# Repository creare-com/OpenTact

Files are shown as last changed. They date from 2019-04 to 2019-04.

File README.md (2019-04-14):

# OpenTact: Open Source Headset
The goal of this project is to provide the design files, electronics, software, and algorithms to allow you to build your own electronic communications headset.  Multiple headset designs are available here.  We hope that this work will help you get to your goal faster, whether it be research and development or simply fun audio hacking!
## Headset Designs
Three headset designs are included.  As shown below, there is the "Ear" headset, the "Low-Profile" (LoPro) headset, and the "Full-Profile" (FullPro) headset.

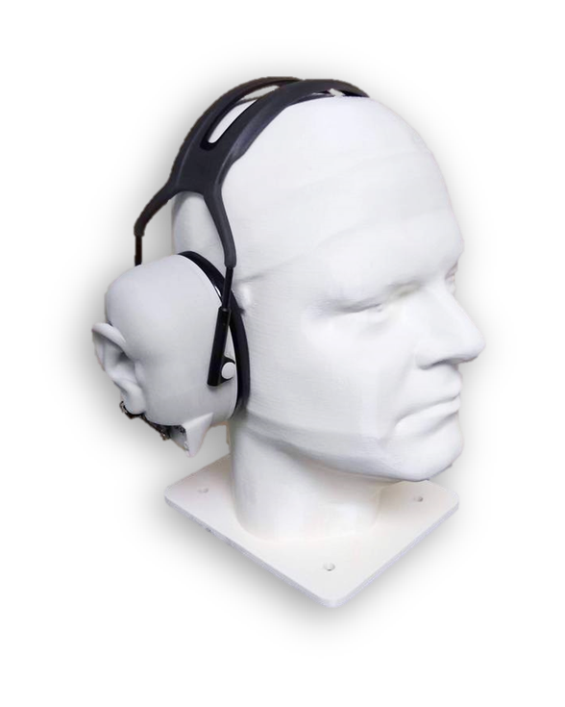
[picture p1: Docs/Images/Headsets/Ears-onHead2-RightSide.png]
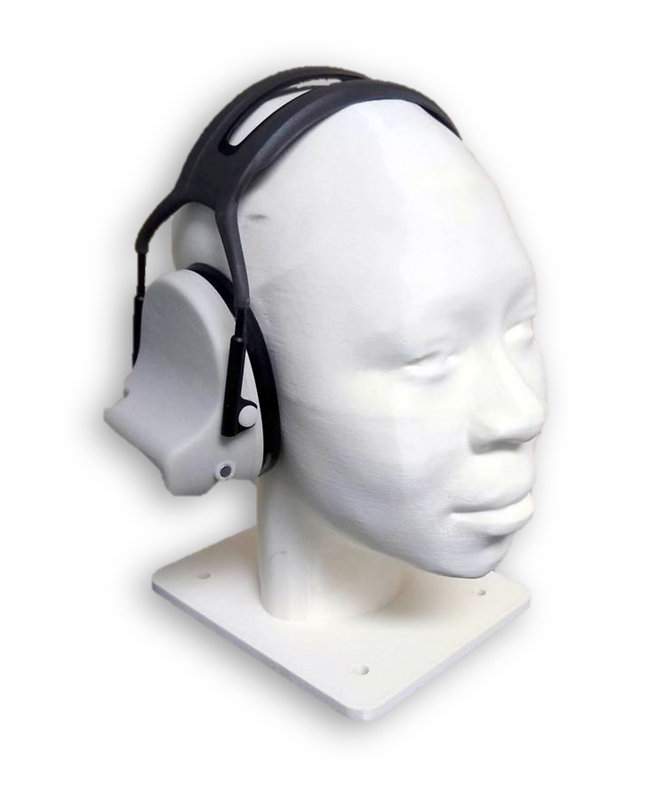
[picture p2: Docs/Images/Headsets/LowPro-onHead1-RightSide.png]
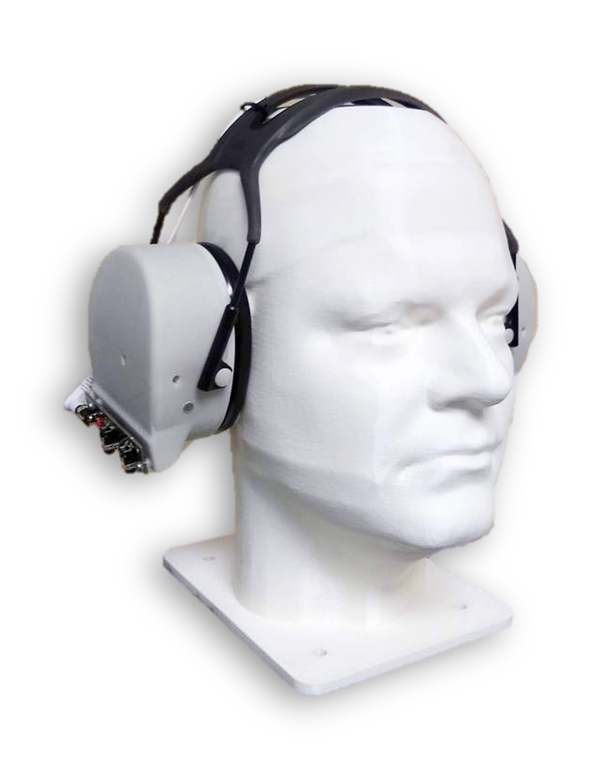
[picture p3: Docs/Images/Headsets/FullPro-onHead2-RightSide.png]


For instructions on how to use this repository to fabricate these headsets, see the [ReadMe.PDF](https://github.com/creare-com/OpenTact/blob/master/ReadMe.pdf)

## License
All of these materials are released under the MIT License.  Use at your own risk.

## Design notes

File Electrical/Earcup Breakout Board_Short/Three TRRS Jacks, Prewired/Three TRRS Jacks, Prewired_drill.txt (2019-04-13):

; NON-PLATED HOLES START AT T1
; THROUGH (PLATED) HOLES START AT T100
M48
INCH
T1C0.129000
T2C0.039361
T100C0.038000
T101C0.015748
%
T1
X015065Y005138
X000959Y000888
T2
X003284Y000871
X017399Y001572
X010174Y000878
X004675Y000871
X003284Y000878
X004674Y000878
X008784Y000878
X017399Y001568
X017399Y002959
X010181Y000871
X017399Y002963
X008791Y000871
T100
X006889Y004888
X001389Y003134
X006889Y003888
X016639Y005388
X001389Y002134
X012639Y005388
X017639Y005388
X001389Y004189
X001389Y005189
X013639Y005388
T101
X014139Y002638
X011889Y002138
X014142Y003890
X003889Y001388
X007887Y003891
X009639Y001388
X010139Y004138
X010889Y004384
X003889Y003638
X004639Y002138
X014889Y002638
X015889Y003539
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

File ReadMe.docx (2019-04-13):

Project: | OpenTact
Title: | Instructions for Building the OpenTact Headset
Date Created: | 4/11/2019

# 1. Contents of the Repository

This repository contains design files that can be used to fabricate headsets with three different styles of earcups. The earcup has a mounting plate for a 40mm speaker and several locations to mount microphones. To preview the earcups, download the eDrawings Viewer (https://www.edrawingsviewer.com/) and open the CAD files under the Mechanical/Preview CAD folder.

## A) Earcup with Pinna: Headset with a plastic, outer ear

## B) Low-Profile Earcup: Headset with low-profile earcups that can be worn under a helmet

## C) Full-Profile Earcup: Headset with earcups similar to off-the-shelf earmuffs

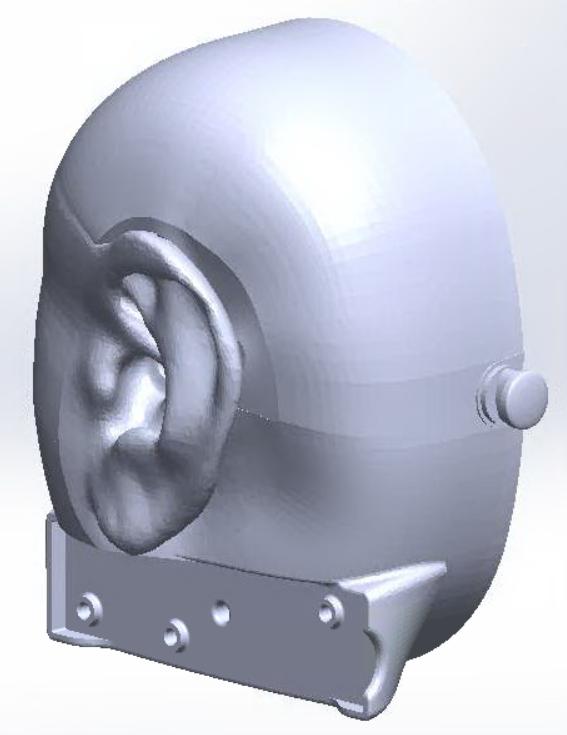
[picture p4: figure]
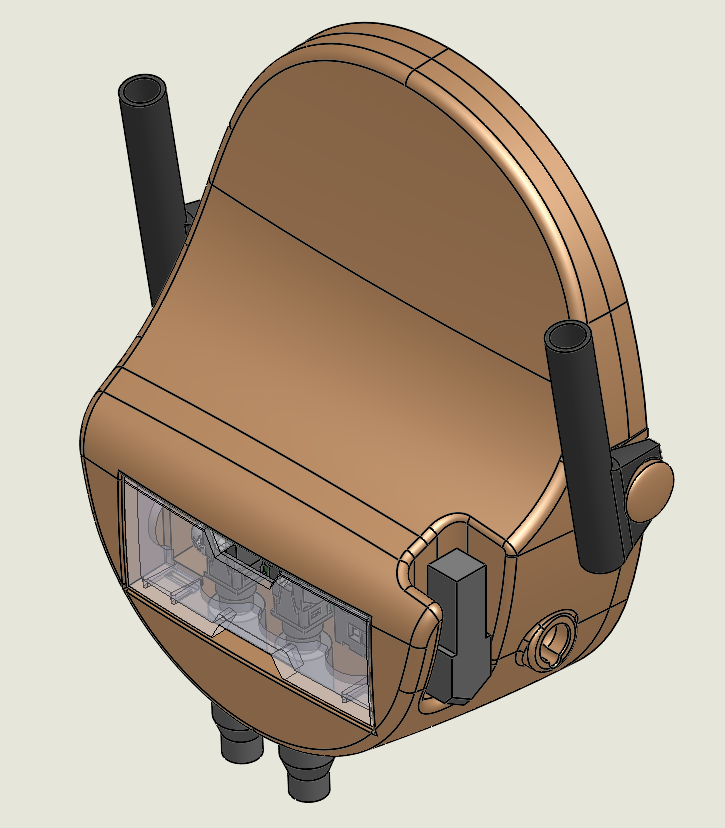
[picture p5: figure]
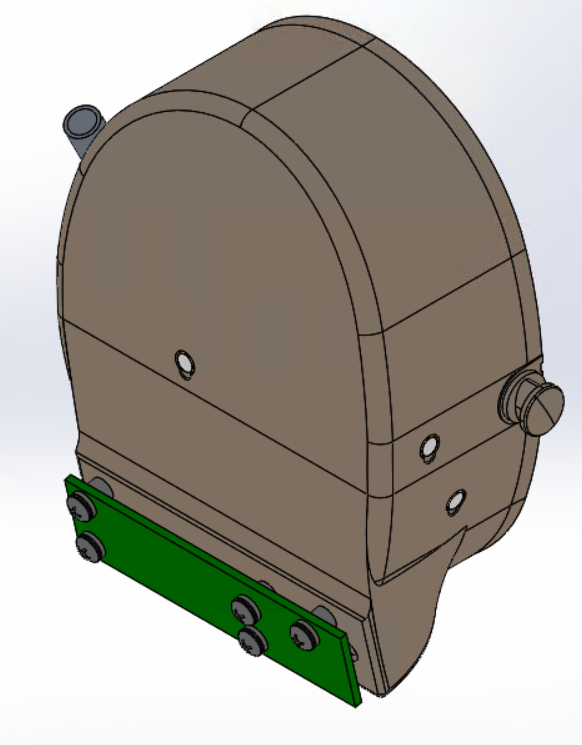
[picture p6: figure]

A B C

## The audio for the headset is processed by the Tympan, which has an audio codec and an Arduino-compatible microcontroller. You can add 2 more additional channels using the AIC Shield, which stacks on top of the Tympan. Two enclosure designs are provide to encompass these boards.

## Tympan Enclosure: Enclosure for the Tympan PCB and battery

## Tympan Enclosure with AIC Shield: Enclosure for the Tympan PCB, battery, and AIC Shield

## The repository is organized by:

## Bill of Materials: List of components and subassemblies

## Mechanical: Solidworks CAD files and STP files for 3D printing

## Electronics: PCB design files and Gerber output files, along with a wiring diagram

## Firmware: Example Arduino sketches written specific for the OpenTact project. For basic sketches on audio processing, start with the Tympan wiki “Getting Started (https://github.com/Tympan/Docs/wiki/Getting-Starting-with-Tympan).”

# 2. Fabricating the Headset Components (also refer to bill of materials)

Mechanical: Most of the mechanical components are 3D-printed using SLS fiber-reinforced nylon (PA12), with the exception of the headband and ear seals, which are taken from a set of commercial ear muffs (3M X4A). The speaker mount accepts 40mm speakers and is compatible with all three earcup styles. If you need to modify the physical components, the CAD design files require Solidworks version 2018 SP4 or later. Otherwise, you can import the STL files and modify them from there.

Electrical: The Tympan processing board can be purchased through https://shop.tympan.org, or fabricated using the design files from this repository. A breakout board is mounted to each earcup to provide a place to solder the mic and speaker wires. The short breakout board is sufficient for projects involving a (1) mic and (1) speaker per side. For more complex projects, the long breakout board accommodates multiple components but requires external jumper wires.

## If using the long breakout board, refer to the wiring diagram in the Electrical folder. Note that the long breakout board is not compatible with the Low-Profile Headset.

## The short breakout board has two sides so that it can be used for both the left and right earcups. Solder (3) TRRS jacks onto the side of the breakout board labeled “J1” in the upper left, which will become the “left” breakout board. These pads correspond to “TRRS-1”, “TRRS-3”, and “TRRS -5”.

## Solder (1) TRRS jack onto the side of the breakout board labeled “J3” in the upper left, which will become the “right” breakout board. These pads correspond to “TRRS-6.”

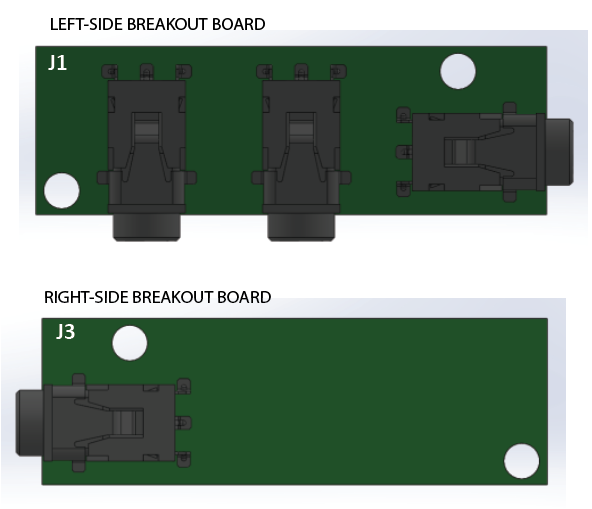
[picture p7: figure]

## Left and right sides of the Short Breakout Board, with TRRS jacks

## If you need to modify the PCBs, the breakout boards for the earcups were created in Fritzing (http://fritzing.org/) and the Tympan PCB and AIC Shield were designed in KiCad (http://kicad-pcb.org/).

# 3. Assembling the Headset

## Microphone: Solder wire leads to the 6mm mic, paying attention to the dot indicating polarity.

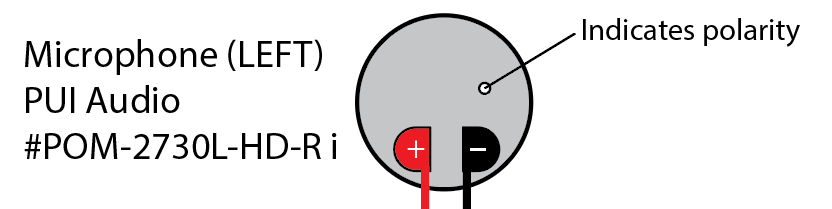
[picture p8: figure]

## In the case of the Earcup with Pinna, the microphone is inserted into the ear canal from inside of the earcup. For the other external microphones, drill out the small pilot hole inside the opening where the microphone will sit to allow wires to be routed inside to the earcup.

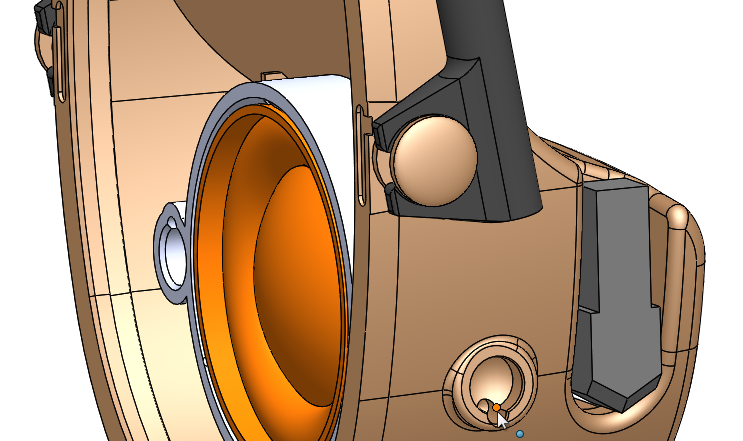
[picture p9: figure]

Drill out pilot hole before inserting the microphone

## Seal the microphone with putty (see BOM) or adhesive, then run the microphone wires through a hole near the bottom of the earcup to the outside, where the breakout board will go. Leave more than 4” of wire outside the earcup to trim back later. Label the wires

## Foam: Trim and insert foam inside the earcups to diffuse the resonating noise from the empty cavity.

Speaker: If using the Low-Profile Earcup, trim back the bottom tab of the speaker mounting plate, as shown in the figure below. Drill a small hole in the middle of the mounting plate to pass wires through, then pass the speaker wires through the mounting plate, then thru the hole near the bottom of the earcup to the outside where the breakout board will go. Leave more than 4” of wire outside the earcup to trim back later. Label the wires. Apply putty (see BOM) to seal the hole in the earcup.

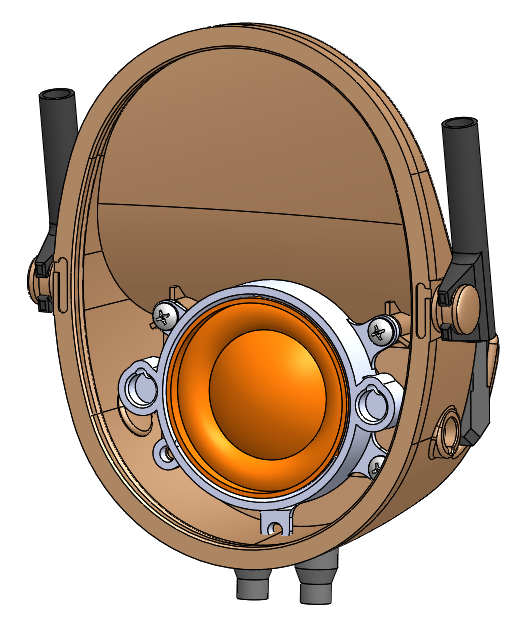
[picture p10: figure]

Trim tab of speaker mount

## Press the speaker into the mounting plate then screw the mounting plate to the earcup. If the speaker is loose inside the mounting plate, apply putty or superglue to secure it.

Ear Seal: Remove the ear seals from the commercial earmuffs and install them onto the new earcups. Hold the earcups against your ears to determine if more foam is needed to diffuse the noise from the empty cavity. Press the ear seal against your face and blow to determine if there are any leaks. Fill any leaks with putty. If you need to remove a stubborn ear seal, use a small screwdriver to pry the ear seal away, inserting a second screwdriver along the gap that is created.

Breakout Boards: Locate the breakout board for the right earcup. Cut the trace indicated in the figure below. Trim the microphone and speaker wires and solder them to the breakout boards. Shown is the outside face of the breakout boards, however, soldering the wires to the inner face provides a cleaner look.

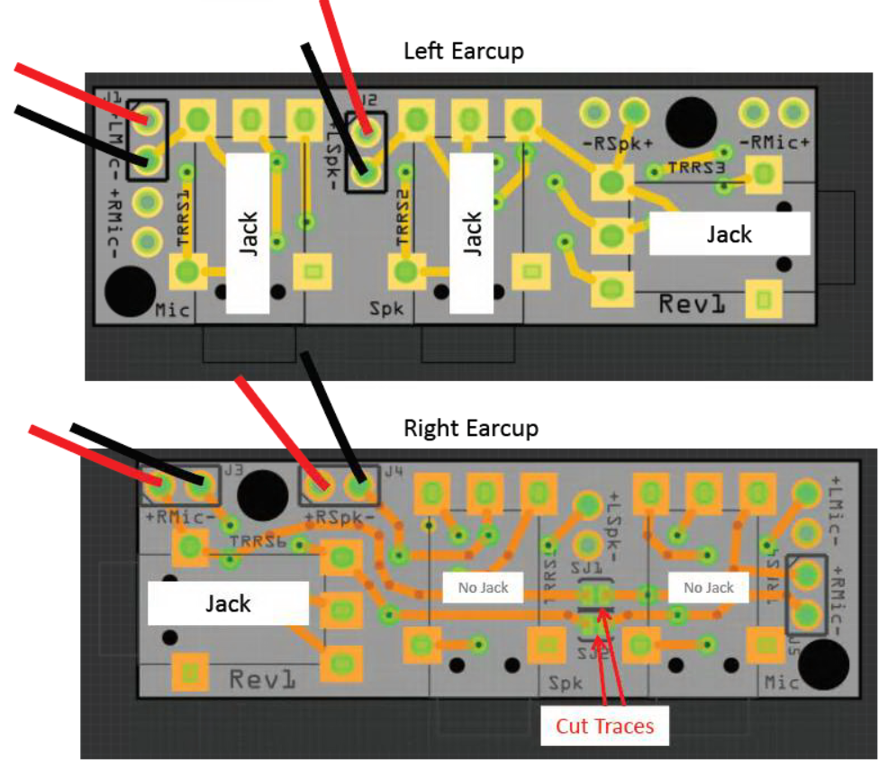
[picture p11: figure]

## Screw the breakout board to the earcup, using washers on top of the board to prevent shorting. If using the long breakout board, place additional plastic washers under the board to provide clearance for the jumper wires.

Cables: The mic and speaker signals from the Tympan are routed to the left earcup using (2) audio cables (3-conductor; TRS). Note that the audio cable with right-angle plugs is 4-conductor (TRRS) and used to bridge the left and right breakout boards. This cable can be shortened (cut and spliced) to better fit the headband.

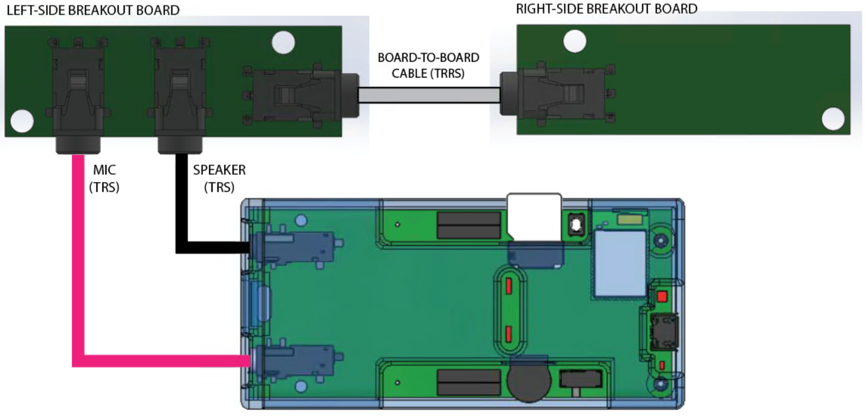
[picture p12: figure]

# 4. Software

Once the components are assembled, follow the “Getting Started (https://github.com/Tympan/Docs/wiki/Getting-Starting-with-Tympan)” guide on the Tympan wiki. This will direct you how to install the Arduino programming environment and the Tympan Audio library. Then move on to the more advanced programs in the Tympan library, or check out the OpenTact-specific programs included in this repository.

OpenTact Readme.docx (Rev-1.1) 1 of 6

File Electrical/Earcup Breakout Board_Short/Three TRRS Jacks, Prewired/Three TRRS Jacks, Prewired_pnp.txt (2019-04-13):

*Pick And Place List
*Company=
*Author=
*eMail=
*
*Project=Three TRRS Jacks, Prewired
*Date=18:40:02
*CreatedBy=Fritzing 0.9.3b.04.19.5c895d327c44a3114e5fcc9d8260daf0cbb52806
*
*
*Coordinates in mm, always center of component
*Origin 0/0=Lower left corner of PCB
*Rotation in degree (0-360, math. pos.)
*
*No;Value;Package;X;Y;Rotation;Side;Name
1;;;2.43811;-2.25756;0;Bottom;Hole3
2;;RC-5325A [SMD];24.0715;-6.07312;-90;Top;TRRS2
3;;;11.7844;-10.5127;0;Bottom;Via13
4;;;13.6894;-6.70265;0;Bottom;Via4
5;;;40.3594;-11.1477;0;Bottom;Via8
6;;;38.3282;-1.2886;0;Bottom;TXT2
7;;;33.579;-11.5736;0;Bottom;TXT6
8;;;35.9217;-9.88076;0;Bottom;Via9
9;;;24.4844;-3.52765;0;Bottom;Via15
10;;RC-5325A [SMD];10.1161;-6.05339;90;Bottom;TRRS4
11;;;1.6819;-6.33256;-90;Bottom;TXT6
12;;;9.87937;-9.24265;0;Bottom;Via14
13;;;38.2662;-13.0526;0;Bottom;Hole5
14;;;33.3699;-11.5316;0;Bottom;TXT6
15;;;6.06937;-9.87765;0;Bottom;Via10
16;;;29.5644;-9.24265;0;Bottom;Via7
17;;RC-5325A [SMD];24.1016;-6.05339;90;Bottom;TRRS5
18;;THT;17.4995;-11.1476;0;Bottom;J2
19;;;35.9144;-6.70265;0;Bottom;Via5
20;;;40.3594;-8.99035;0;Bottom;Via3
21;;;43.5903;-11.6488;0;Bottom;TXT6
22;;;1.81116;-12.0857;-90;Bottom;TXT6
23;;RC-5325A [SMD];40.354;-5.75394;180;Top;TRRS3
24;;;11.7844;-5.43265;0;Bottom;Via1
25;;sj_2s-trace;16.9915;-6.70256;180;Bottom;SJ1
26;;;15.2905;-10.9798;90;Bottom;TXT6
27;;THT;3.52947;-11.911;0;Bottom;J1
28;;sj_2s-trace;16.9915;-4.79756;180;Bottom;SJ2
29;;;1.30292;-6.61144;90;Bottom;TXT6
30;;THT;3.52947;-6.69211;0;Bottom;J5
31;;;15.9745;-11.0578;-90;Bottom;TXT6
32;;;5.09801;-0.981822;0;Bottom;TXT6
33;;;27.6582;-11.1361;0;Bottom;Via20
34;;;18.9077;-0.953036;0;Bottom;TXT6
35;;;1.37521;-11.6223;90;Bottom;TXT6
36;;;18.8234;-1.05157;0;Bottom;TXT6
37;;;30.1994;-5.43265;0;Bottom;Via2
38;;;38.274;-1.13084;0;Bottom;TXT2
39;;;20.0334;-9.88358;0;Bottom;Via11
40;;;5.13193;-0.929081;0;Bottom;TXT6
41;;RC-5325A [SMD];10.1015;-6.07312;-90;Top;TRRS1
42;;;25.7544;-7.97265;0;Bottom;Via18
43;;RC-5325A [SMD];40.354;-5.75704;0;Bottom;TRRS6
44;;;23.8494;-10.5127;0;Bottom;Via16
45;;THT;33.3745;-13.6876;90;Bottom;J4
46;;THT;43.5345;-13.6876;90;Bottom;J3
47;;;43.5333;-11.5457;0;Bottom;TXT6
48;;;9.87937;-3.52765;0;Bottom;Via12
49;;;37.8194;-6.70265;0;Bottom;Via6
50;;;25.7544;-10.5127;0;Bottom;Via19

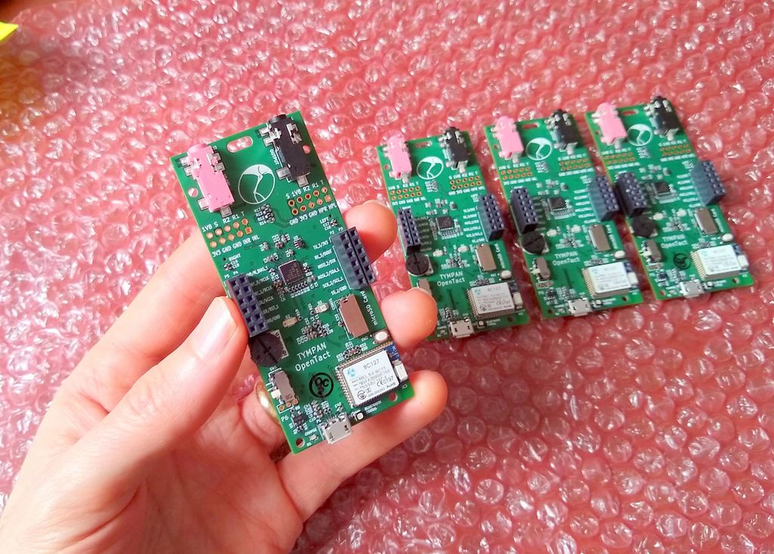
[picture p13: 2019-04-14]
Docs/Images/Electronics/Tympan RevD3 - Hand.jpg

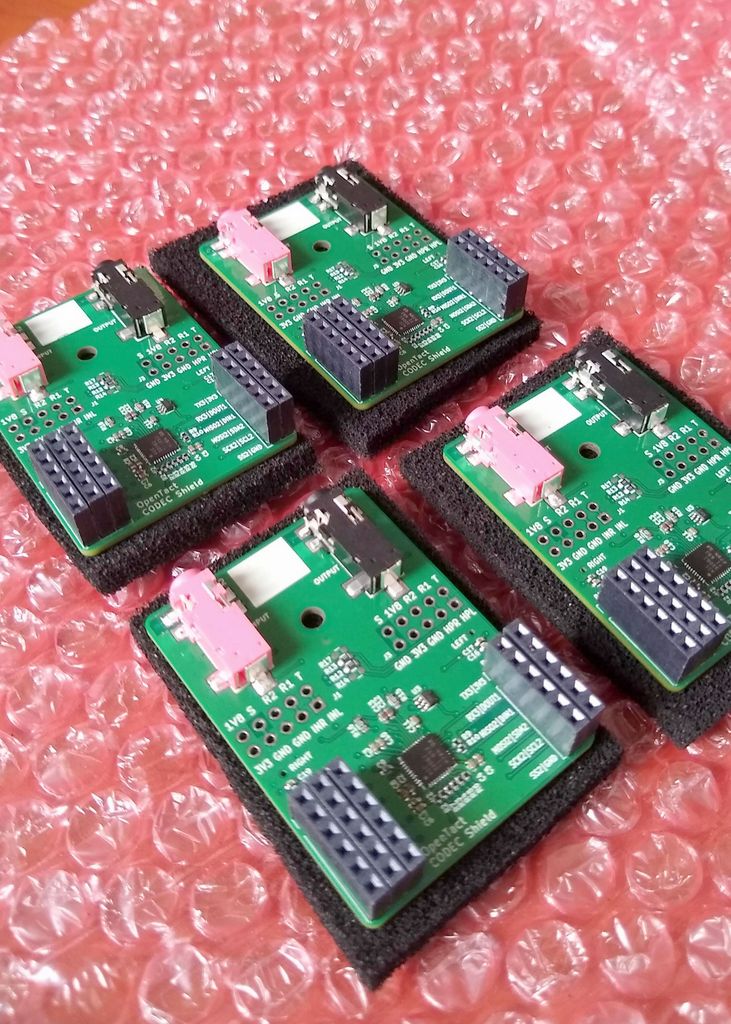
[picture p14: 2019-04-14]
Docs/Images/Electronics/Tympan AIC Shields.jpg

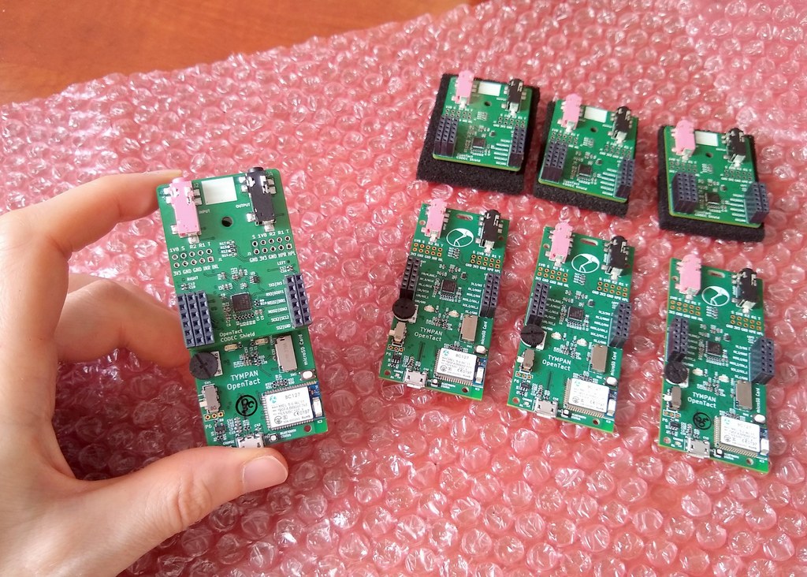
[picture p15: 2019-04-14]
Docs/Images/Electronics/Tympan 4-Channel.jpg

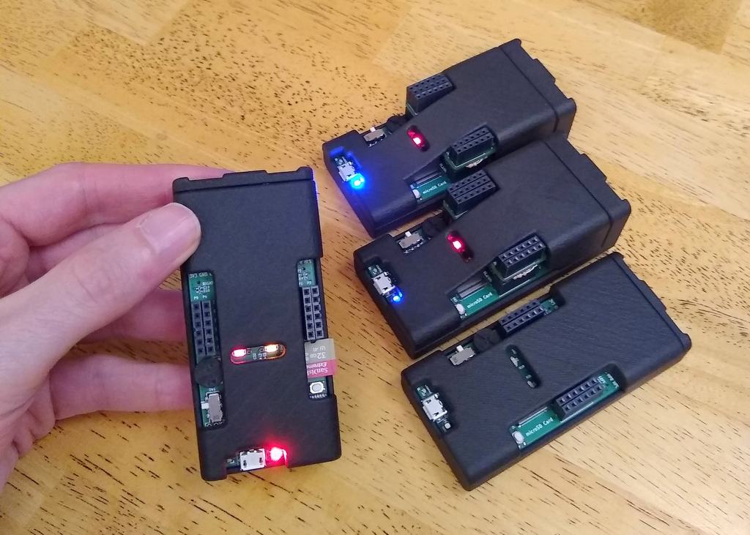
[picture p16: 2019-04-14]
Docs/Images/Electronics/Tympan_RevD3_inEnclosures_Hand.jpg

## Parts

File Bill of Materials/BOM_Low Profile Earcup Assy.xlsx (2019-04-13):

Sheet: EARCUP_WITH PINNA
Project: | OpenTact
Title: | Bill of Materials for EARCUP_WITH PINNA
Date Created: | 2019-04-11
Earcup Revision: | C
Notes: | BOM captures a full headset (left and right).
Line # | Title | Description | Manufacturer | Manuf. Part # | Vendor | Vendor Part # | Unit Cost | Quantity | Subtotal | Notes
1 | EARCUP_BODY_LEFT_WITH_PINNA_REV-C | 3D-printed earcup - Left | PROTOLABS | N/A | N/A | N/A | $128.00 | 1 | $128.00 | Selective Laser Sintering; PA 12 40% Glass Filled Nylon; 0.004" layers
2 | EARCUP_BODY_RIGHT_WITH_PINNA_REV-C | 3D-printed earcup - Right | PROTOLABS | N/A | N/A | N/A | $128.00 | 1 | $128.00 | Selective Laser Sintering; PA 12 40% Glass Filled Nylon; 0.004" layers
4 | PLASTITE SCREW_SZ-4_0250-LG_SS | Screw | N/A | N/A | McMaster | 99461A282 (https://www.mcmaster.com/99461a282) | $0.38 | 10 | $3.75 | Screws for mouning PCB and speaker mounts
5 | WASHER_SZ-4_NYLON | Plastic Washer | N/A | N/A | McMaster | 90295A059 (https://www.mcmaster.com/90295A059) | $0.05 | 4 | $0.20
6 | POLYURETHANE_FOAM_24x24x0500-THK | Foam for diffusing sound | N/A | N/A | McMaster | 86225K15 (https://www.mcmaster.com/86225K15) | $13.86 | 0.1 | $1.39
7 | HEADBAND & 2_EARSEALS_27DB | Parts from retail earmuffs | 3M | X4A | Amazon | B00CPCHADQ (https://www.amazon.com/Peltor-Over-Head-Earmuffs-Black/dp/B00CPCHADQ?s=gateway) | $25.94 | 1 | $25.94
8 | MOUNT_FOR_40MM_SPEAKER | Speaker mount | PROTOLABS | N/A | N/A | N/A | $34.45 | 2 | $68.89 | Selective Laser Sintering; PA 12 40% Glass Filled Nylon; 0.004" layers
9 | SEALING_PUTTY | Putty for sealing the earcup | Parker | PP-22 | Grainger | 4E307 | $14.68 | 0.1 | $1.47
10 | SPEAKER_40MM-OD | Speaker | Beats | Studio 2.0 | EarPhoneDIYLabs (https://www.earphonediylabs.com/index.php/product-category/headphone-drivers/) | N/A | $16.99 | 2 | $33.98
11 | MIC_ELECTRET_6MM-OD | Microphone | PUI Audio | POM-2730L-HD-R | Digikey | 668-1598-ND (https://www.digikey.com/product-detail/en/pui-audio-inc/POM-2730L-HD-R/668-1598-ND/7898330) | $3.14 | 2 | $6.28
12 | AUDIO_CABLE_3.5MM_TRS_MALE-MALE_3FT_RED | Mic Cable | IXCC | N/A | Amazon | B077VPB1WZ (https://www.amazon.com/iXCC-Nylon-Braided-Connectors-Tangle-Free-Smartphones/dp/B077VPB1WZ?s=electronics) | $3.50 | 1 | $3.50
13 | AUDIO_CABLE_3.5MM_TRS_MALE-MALE_3FT_BLK | Speaker Cable | IXCC | N/A | Amazon | B06XWWY7NW (https://www.amazon.com/iXCC-Nylon-Braided-Connectors-Tangle-Free-Smartphones/dp/B06XWWY7NW?s=electronics) | $4.00 | 1 | $4.00
14 | AUDIO_CABLE_3.5MM_TRRS_MALE-MALE_?FT_WHT | Left-Right Cable | N/A | N/A | Sparkfun | CAB-14164 (https://www.sparkfun.com/products/14164) | $2.50 | 1 | $2.50 | Cable requires shortening to fit between right and left earcup
15 | SHORT_BREAKOUT_BOARD | Breakout Board | OSH Park (https://oshpark.com/) | N/A | N/A | N/A | $3.67 | 2 | $7.33 | 2-Layer FR4
16 | LONG_BREAKOUT_BOARD | Breakout Board | OSH Park (https://oshpark.com/) | N/A | N/A | N/A | $6.13 | 0 | $0.00 | Optional 2-Layer FR4
17 | AUDIO_JACK_3.5MM_TRRS_RA | Audio Jack (TRRS) | LUMBERG | 1503 13 VP3 | NEWARK | 54M1764 (https://www.newark.com/lumberg/1503-13-vp3/connector-rca-phono-jack-4-position/dp/54M1764) | $1.20 | 4 | $4.80
TOTAL |  |  |  |  |  |  |  |  | $420.01

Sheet: EARCUP_LOW-PROFILE
Project: | OpenTact
Title: | Bill of Materials for EARCUP_LOW PROFILE
Date Created: | 2019-04-11
Earcup Revision: | C
Notes: | BOM captures a full headset (left and right).
Line # | Title | Description | Manufacturer | Manuf. Part # | Vendor | Vendor Part # | Unit Cost | Quantity | Subtotal | Notes
1 | EARCUP_BODY_LEFT_LOW_PROFILE_REV-C | 3D-printed earcup - Left | PROTOLABS | N/A | N/A | N/A | $135.97 | 1 | $135.97 | Selective Laser Sintering; PA 12 40% Glass Filled Nylon; 0.004" layers
2 | EARCUP_BODY_RIGHT_LOW_PROFILE_REV-C | 3D-printed earcup - Right | PROTOLABS | N/A | N/A | N/A | $135.97 | 1 | $135.97 | Selective Laser Sintering; PA 12 40% Glass Filled Nylon; 0.004" layers
3 | PCB_COVER_LOW_PROFILE | 3D-printed cover | PROTOLABS | N/A | N/A | N/A | $28.35 | 2 | $56.70 | Selective Laser Sintering; PA 12 40% Glass Filled Nylon; 0.004" layers
4 | PLASTITE SCREW_SZ-4_0250-LG_SS | Screw | N/A | N/A | McMaster | 99461A282 (https://www.mcmaster.com/99461a282) | $0.38 | 10 | $3.75 | Screws for mouning PCB and speaker mounts
5 | WASHER_SZ-4_NYLON | Plastic Washer | N/A | N/A | McMaster | 90295A059 (https://www.mcmaster.com/90295A059) | $0.05 | 4 | $0.20
6 | POLYURETHANE_FOAM_24x24x0500-THK | Foam for diffusing sound | N/A | N/A | McMaster | 86225K15 (https://www.mcmaster.com/86225K15) | $13.86 | 0.1 | $1.39
7 | HEADBAND & 2_EARSEALS_27DB | Parts from retail earmuffs | 3M | X4A | Amazon | B00CPCHADQ (https://www.amazon.com/Peltor-Over-Head-Earmuffs-Black/dp/B00CPCHADQ?s=gateway) | $25.94 | 1 | $25.94
8 | MOUNT_FOR_40MM_SPEAKER | Speaker mount | PROTOLABS | N/A | N/A | N/A | $34.45 | 2 | $68.89 | Selective Laser Sintering; PA 12 40% Glass Filled Nylon; 0.004" layers NOTE! BOTTOM SPEAKER MOUNT MUST BE TRIMMED
9 | SEALING_PUTTY | Putty for sealing the earcup | Parker | PP-22 | Grainger | 4E307 | $14.68 | 0.1 | $1.47
10 | SPEAKER_40MM-OD | Speaker | Beats | Studio 2.0 | EarPhoneDIYLabs (https://www.earphonediylabs.com/index.php/product-category/headphone-drivers/) | N/A | $16.99 | 2 | $33.98
11 | MIC_ELECTRET_6MM-OD | Microphone | PUI Audio | POM-2730L-HD-R | Digikey | 668-1598-ND (https://www.digikey.com/product-detail/en/pui-audio-inc/POM-2730L-HD-R/668-1598-ND/7898330) | $3.14 | 2 | $6.28
12 | AUDIO_CABLE_3.5MM_TRS_MALE-MALE_3FT_RED | Mic Cable | IXCC | N/A | Amazon | B077VPB1WZ (https://www.amazon.com/iXCC-Nylon-Braided-Connectors-Tangle-Free-Smartphones/dp/B077VPB1WZ?s=electronics) | $3.50 | 1 | $3.50
13 | AUDIO_CABLE_3.5MM_TRS_MALE-MALE_3FT_BLK | Speaker Cable | IXCC | N/A | Amazon | B06XWWY7NW (https://www.amazon.com/iXCC-Nylon-Braided-Connectors-Tangle-Free-Smartphones/dp/B06XWWY7NW?s=electronics) | $4.00 | 1 | $4.00
14 | AUDIO_CABLE_3.5MM_TRRS_MALE-MALE_?FT_WHT | Left-Right Cable | N/A | N/A | Sparkfun | CAB-14164 (https://www.sparkfun.com/products/14164) | $2.50 | 1 | $2.50 | Cable requires shortening to fit between right and left earcup
15 | SHORT_BREAKOUT_BOARD | Breakout Board | OSH Park (https://oshpark.com/) | N/A | N/A | N/A | $3.67 | 2 | $7.33 | 2-Layer FR4
16 | AUDIO_JACK_3.5MM_TRRS_RA | Audio Jack (TRRS) | LUMBERG | 1503 13 VP3 | NEWARK | 54M1764 (https://www.newark.com/lumberg/1503-13-vp3/connector-rca-phono-jack-4-position/dp/54M1764) | $1.20 | 4 | $4.80
TOTAL |  |  |  |  |  |  |  |  | $492.65

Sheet: EARCUP_FULL-PROFILE
Project: | OpenTact
Title: | Bill of Materials for EARCUP_FULL-PROFILE
Date Created: | 2019-04-11
Earcup Revision: | C
Notes: | BOM captures a full headset (left and right).
Line # | Title | Description | Manufacturer | Manuf. Part # | Vendor | Vendor Part # | Unit Cost | Quantity | Subtotal | Notes
1 | EARCUP_BODY_LEFT_FULL_PROFILE_REV-C | 3D-printed earcup - Left | PROTOLABS | N/A | N/A | N/A | $165.00 | 1 | $165.00 | Selective Laser Sintering; PA 12 40% Glass Filled Nylon; 0.004" layers
2 | EARCUP_BODY_RIGHT_FULL_PROFILE_REV-C | 3D-printed earcup - Right | PROTOLABS | N/A | N/A | N/A | $165.00 | 1 | $165.00 | Selective Laser Sintering; PA 12 40% Glass Filled Nylon; 0.004" layers
4 | PLASTITE SCREW_SZ-4_0250-LG_SS | Screw | N/A | N/A | McMaster | 99461A282 (https://www.mcmaster.com/99461a282) | $0.38 | 10 | $3.75 | Screws for mouning PCB and speaker mounts
5 | WASHER_SZ-4_NYLON | Plastic Washer | N/A | N/A | McMaster | 90295A059 (https://www.mcmaster.com/90295A059) | $0.05 | 4 | $0.20
6 | POLYURETHANE_FOAM_24x24x0500-THK | Foam for diffusing sound | N/A | N/A | McMaster | 86225K15 (https://www.mcmaster.com/86225K15) | $13.86 | 0.1 | $1.39
7 | HEADBAND & 2_EARSEALS_27DB | Parts from retail earmuffs | 3M | X4A | Amazon | B00CPCHADQ (https://www.amazon.com/Peltor-Over-Head-Earmuffs-Black/dp/B00CPCHADQ?s=gateway) | $25.94 | 1 | $25.94
8 | MOUNT_FOR_40MM_SPEAKER | Speaker mount | PROTOLABS | N/A | N/A | N/A | $34.45 | 2 | $68.89 | Selective Laser Sintering; PA 12 40% Glass Filled Nylon; 0.004" layers
9 | SEALING_PUTTY | Putty for sealing the earcup | Parker | PP-22 | Grainger | 4E307 | $14.68 | 0.1 | $1.47
10 | SPEAKER_40MM-OD | Speaker | Beats | Studio 2.0 | EarPhoneDIYLabs (https://www.earphonediylabs.com/index.php/product-category/headphone-drivers/) | N/A | $16.99 | 2 | $33.98
11 | MIC_ELECTRET_6MM-OD | Microphone | PUI Audio | POM-2730L-HD-R | Digikey | 668-1598-ND (https://www.digikey.com/product-detail/en/pui-audio-inc/POM-2730L-HD-R/668-1598-ND/7898330) | $3.14 | 2 | $6.28
12 | AUDIO_CABLE_3.5MM_TRS_MALE-MALE_3FT_RED | Mic Cable | IXCC | N/A | Amazon | B077VPB1WZ (https://www.amazon.com/iXCC-Nylon-Braided-Connectors-Tangle-Free-Smartphones/dp/B077VPB1WZ?s=electronics) | $3.50 | 1 | $3.50
13 | AUDIO_CABLE_3.5MM_TRS_MALE-MALE_3FT_BLK | Speaker Cable | IXCC | N/A | Amazon | B06XWWY7NW (https://www.amazon.com/iXCC-Nylon-Braided-Connectors-Tangle-Free-Smartphones/dp/B06XWWY7NW?s=electronics) | $4.00 | 1 | $4.00
14 | AUDIO_CABLE_3.5MM_TRRS_MALE-MALE_?FT_WHT | Left-Right Cable | N/A | N/A | Sparkfun | CAB-14164 (https://www.sparkfun.com/products/14164) | $2.50 | 1 | $2.50 | Cable requires shortening to fit between right and left earcup
15 | SHORT_BREAKOUT_BOARD | Breakout Board | OSH Park (https://oshpark.com/) | N/A | N/A | N/A | $3.67 | 2 | $7.33 | 2-Layer FR4
16 | LONG_BREAKOUT_BOARD | Breakout Board | OSH Park (https://oshpark.com/) | N/A | N/A | N/A | $6.13 | 0 | $0.00 | Optional 2-Layer FR4
17 | AUDIO_JACK_3.5MM_TRRS_RA | Audio Jack (TRRS) | LUMBERG | 1503 13 VP3 | NEWARK | 54M1764 (https://www.newark.com/lumberg/1503-13-vp3/connector-rca-phono-jack-4-position/dp/54M1764) | $1.20 | 4 | $4.80
TOTAL |  |  |  |  |  |  |  |  | $494.01

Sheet: TYMPAN
Project: | OpenTact
Title: | Bill of Materials for Tympan Assy
Date Created: | 2019-04-11
Line # | Title | Description | Manufacturer | Manuf. Part # | Vendor | Vendor Part # | Unit Cost | Quantity | Subtotal | Notes
1 | TYMPAN PCB | Audio Processor | Tympan | Tympan Rev D (https://shop.tympan.org/) | Tympan | Tympan Rev D (https://shop.tympan.org/) | $299.00 | 1 | $299.00
2 | ENCLOSURE FOR TYMPAN_TOP_REV-B | Enclosure | Protolabs | N/A | N/A | N/A | $55.58 | 1 | $55.58 | Selective Laser Sintering; PA 12 in Black; 0.004" layers
3 | ENCLOSURE FOR TYMPAN_BOTTOM_REV-B | Enclosure | Protolabs | N/A | N/A | N/A | $64.43 | 1 | $64.43 | Selective Laser Sintering; PA 12 in Black; 0.004" layers
4 | TYMPAN AIC SHIELD | Audio Shield PCB | Tympan | Tympan AIC Shield | N/A | Tympan AIC Shield | $0.00 | 0 | $0.00 | Optional audio shield that adds two additonal channels
5 | ENCLOSURE FOR TYMPAN WITH SHIELD_TOP_REV-B | Enclosure | Tympan | N/A | N/A | N/A | $77.73 | 0 | $0.00 | Optional; Selective Laser Sintering; PA 12 in Black; 0.004" layers
6 | ENCLOSURE FOR TYMPAN WITH SHIELD_BOTTOM_REV-B | Enclosure | Tympan | N/A | N/A | N/A | $87.08 | 0 | $0.00 | Optional; Selective Laser Sintering; PA 12 in Black; 0.004" layers
TOTAL |  |  |  |  |  |  |  |  | $419.01

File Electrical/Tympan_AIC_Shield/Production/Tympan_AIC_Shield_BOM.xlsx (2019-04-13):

Item | Reference | Package | Quantity | Value | Manufacturer | Part Number | Notes
1 | C23,C2,C8,C12,C13,C24,C25,C26 | C_0402 | 8 | 2.2uF | Murata | GRT155C71A225KE13D
2 | C3,C5,C7,C10,C16,C18 | C_0402 | 6 | 0.1uF | TDK Corporation | C1005X7R1H104K050BB
3 | C4,C6,C11 | C_0402 | 3 | 10uF | Murata | GRM155C80J106ME11J
4 | C9,C17,C19 | C_0402 | 3 | 1uF | Murata | GRM155C81C105KE15D
5 | J1 | SJ-3523-SMT-TR | 1 | Phone Out | CUI Inc | SJ-3523-SMT-TR
6 | J2 | SJ-3524-SMT-TR | 1 | Mic In | CUI Inc | SJ-3524-SMT-TR-PI
7 | MIC2,MIC1 | SPM0687LR5H-1 | 2 | DNP | DNP | DNP | DNP
8 | P5,P6 | Pin_Header_Straight_1x06_Pitch2.54mm | 2 | CONN_01X06 | Samtec | SSW-106-01-G-S
9 | P3,P4,P2,P1 | Pin_Header_Straight_1x06_Pitch2.54mm | 4 | CONN_01X06 | Samtec | SSW-106-03-T-S
10 | R1,R8 | R_0402 | 2 | 4K7 | Yageo | RC0603FR-074K7L
11 | R12,R13 | C_0603 | 2 | 0R | Vishay Dale | CRCW06030000Z0EA
12 | R14,R17 | C_0603 | 2 | DNP | DNP | DNP | DNP
13 | R15,R16 | C_0603 | 2 | 2.2K | Yageo | RC0603FR-072K2L
14 | R2,R3,R4,R5,R6,R7,R9,R10 | R_0402 | 8 | 33R | Yageo | RC0402FR-0733RL
15 | U2 | UQFN-40-1EP_5x5mm_Pitch0.4mm | 1 | CODEC | Texas Instrument | TLV320AIC3206IRSBT
16 | U3 | SOT-353_SC-70-5 | 1 | Analog Switch IC | Texas Instrument | TS5A3166DCKR

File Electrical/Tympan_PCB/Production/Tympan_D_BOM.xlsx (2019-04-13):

Item | Reference | Package | Quantity | Value | Manufacturer | Part Number | Notes
1 | BT1 | 4UCON-0217-20519 | 1 | 4UCON-20519 | 4UCON | 20519 | Consigned by Solutions
2 | C1,C3,C5,C7,C10,C14,C16,C18,C28,C29,C42 | C_0402 | 11 | 0.1uF | TDK Corporation | C1005X7R1H104K050BB
3 | C2,C8,C12,C13,C23,C24,C25,C26,C27,C32,C33,C37,C39 | C_0402 | 13 | 2.2uF | Murata | GRT155C71A225KE13D
4 | C30,C31 | C_0402 | 2 | 10nF | Yageo | AC0402KPX7R9BB103
5 | C35 | C_0402 | 1 | 4.7uF | TDK Corporation | C1005X5R1A475K050BC
6 | C4,C6,C11,C15 | C_0402 | 4 | 10uF | Murata | GRM155C80J106ME11J
7 | C40 | C_0402 | 1 | 15pF | Wurth | 885012005008
8 | C41 | C_0402 | 1 | 22nF | Wurth | 885012205014
9 | C9,C17,C19,C20,C21,C22,C34 | C_0402 | 7 | 1uF | Murata | GRM155C81C105KE15D
10 | CONN1 | MOLEX_47571-0001 | 1 | 8_PIN_microSD | Molex | 47571-0001
11 | D1 | ABHB1608S | 1 | 2 color LED | Everlight | 18-225SURSYGC/S530-A4/E4/TR8
12 | D2 | C_1206 | 1 | LED Red | Lite-On | LTST-C150EKT
13 | D3 | C_1206 | 1 | LED Amber | Lite-On | LTST-C150AKT
14 | D4,D5 | ACDBA340-HF | 2 | Shottkey | Comchip | ACDBA340-HF
15 | D6 | CLMVB-FKA-CFHEHLCBB7a363 | 1 | Led_RGB_CA | Cree | CLMVB-FKA-CFHEHLCBB7a363
16 | F1 | C_1206 | 1 | FUSE | Bell Fuse | C1Q 1
17 | IC1 | BGA-144-1mm | 1 | ARM | NXP | MK66FX1M0VMD18
18 | IC2 | QFN-16-1EP_3x3mm_Pitch0.5mm | 1 | MKL02Z32VFG4 | PJRC | IC_MKL02Z32_QFN16 | Consigned by Solutions
19 | IC3 | BC127 | 1 | BC127 | Sierra Wireless | BC127-1103383
20 | J1 | SJ-3523-SMT-TR | 1 | Phone Out | CUI Inc | SJ-3523-SMT-TR
21 | J2 | SJ-3524-SMT-TR | 1 | Mic In | CUI Inc | SJ-3524-SMT-TR-PI
22 | L1,L2 | C_0402 | 2 | 600R | TDK Corporation | MMZ1005S601HT000
23 | L3 | C_0603 | 1 | 1K | Murata | BLM18KG102SH1D
24 | MIC2,MIC1 | SPM0687LR5H-1 | 2 | MEMS Microphone | Knowles | SPM0687LR5H-1
25 | P1 | 10118193_microUSB | 1 | USB_OTG | Amphenol | 10118193-0001LF
26 | P3,P4,P5,P2 | Pin_Header_Straight_1x06_Pitch2.54mm | 4 | CONN_01X06 | Samtec | SSW-106-01-G-S
27 | P6 | Pin_Header_Straight_1x03_Pitch2.00mm | 1 | DNP | DNP | DNP | DNP
28 | R12,R13 | C_0603 | 2 | 0R | Vishay Dale | CRCW06030000Z0EA
29 | R14,R17 | C_0603 | 2 | DNP | DNP | DNP | DNP
30 | R15,R16 | C_0603 | 2 | 2.2K | Yageo | RC0603FR-072K2L
31 | R18,R21 | R_0402 | 2 | 240R | Yageo | RC0402JR-07240RL
32 | R19,R20,R32,R33,R1,R11 | R_0402 | 6 | 1K | Vishay Dale | CRCW04021K00FKED
33 | R23 | R_0402 | 1 | 100K | Vishay Dale | CRCW0402100KFKED
34 | R25,R34,R35,R36 | R_0402 | 4 | 470R | Yageo | RC0402FR-07470RL
35 | R30,R31 | R_0402 | 2 | 10K | Yageo | RC0402FR-0710KL
36 | R6,R2,R3,R4,R5,R7,R9,R10,R26,R27 | R_0402 | 10 | 33R | Yageo | RC0402FR-0733RL
37 | R8 | R_0402 | 1 | 2.2K | Yageo | RC0402JR-0722KL
38 | RV1 | Pin_Header_Straight_1x03_Pitch2.54mm | 1 | POT | Bourns | 3352T-1-103L
39 | SW1 | CL-SB-22A | 1 | Slide Switch | Nidec Copal | CL-SB-22A-11T
40 | SW2 | PTS810 | 1 | TACT_SWITCH | C&K | PTS810 SJK 250 SMTR LFS
41 | U1 | SOT-23-5 | 1 | 3V3 Regulator | Diodes Inc | AP2210K-3.3TRG1
42 | U2 | UQFN-40-1EP_5x5mm_Pitch0.4mm | 1 | CODEC | Texas Instrument | TLV320AIC3206IRSBT
43 | U3 | SOT-353_SC-70-5 | 1 | Analog Switch IC | Texas Instrument | TS5A3166DCKR
44 | U4 | SOT-23-5 | 1 | 1V8 Regulator | Texas Instrument | LP5907MFX-1.8/NOPB
45 | U5 | SOT-23-5 | 1 | LiPo Charge IC | Microchip | MCP73831T-2DCI/OT
46 | Y1 | LFXTAL009678 | 1 | 32.768kHz | IQD | LFXTAL009678Reel
47 | Y2 | FA_238_16.0000MB_K3 | 1 | 16MHz | Epson | FA_238_16.0000MB_K3

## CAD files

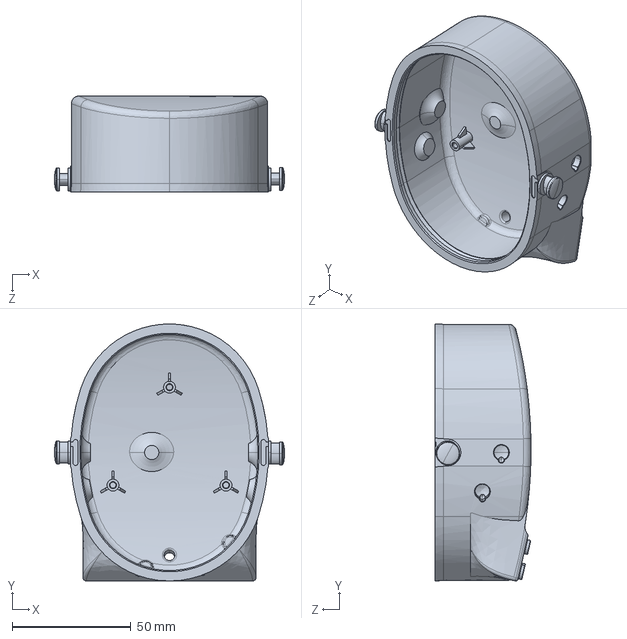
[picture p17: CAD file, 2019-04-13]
Mechanical/Earcup_Full-Profile/Export/Rev-C/EARCUP_BODY_RIGHT_FULL-PROFILE_REV-C.STEP
96.9 x 108.3 x 40.5 mm

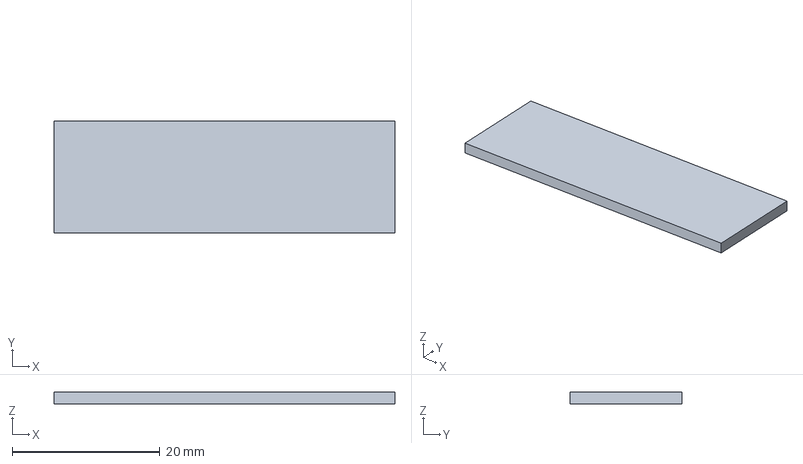
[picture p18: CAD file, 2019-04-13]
Electrical/Earcup Breakout Board_Short/CAD/02-Earcup TRRS Simple PCB R1.step
46.2 x 15.2 x 1.60 mm

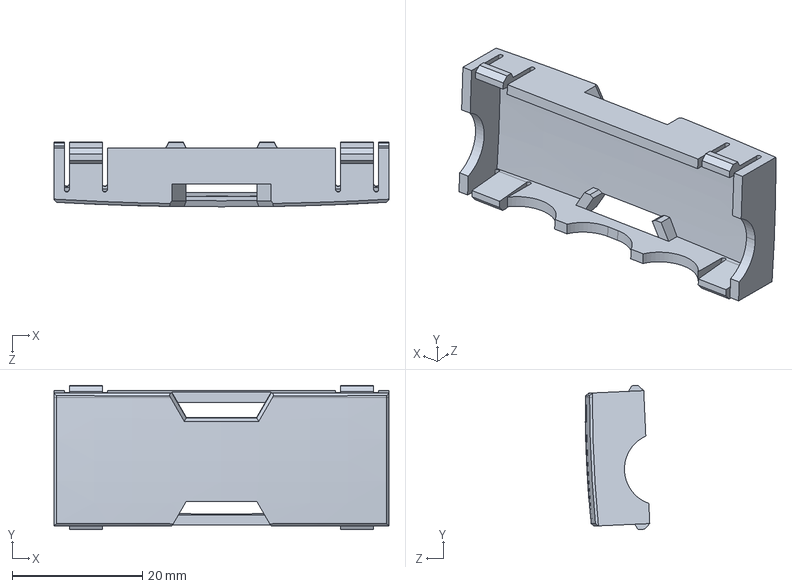
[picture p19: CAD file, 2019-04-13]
Mechanical/Earcup_Low-Profile/Export/REV-C/PCB_COVER_LOW_PROFILE.STEP
51.4 x 22.1 x 9.91 mm

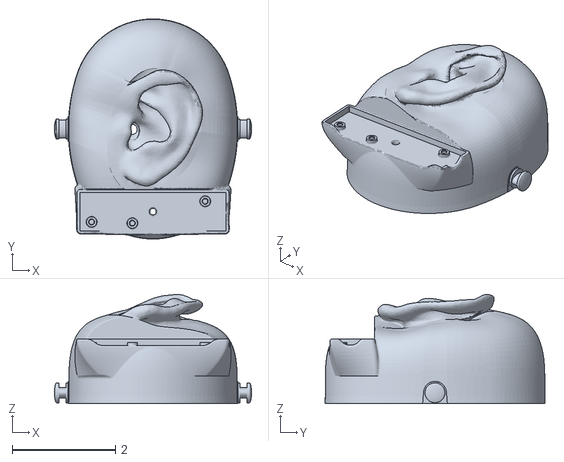
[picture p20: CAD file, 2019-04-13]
Mechanical/Earcup_with Pinna/Export/Rev-C/EARCUP_W_PINNA_ LEFT_REV-C.stl
3.82 x 4.26 x 2.11

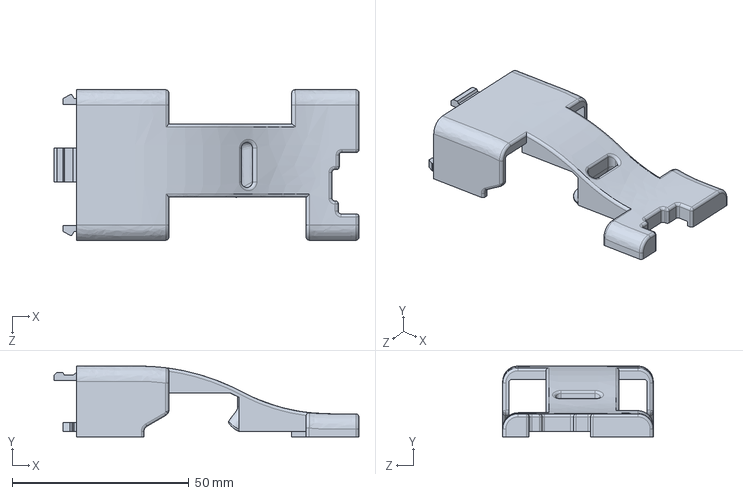
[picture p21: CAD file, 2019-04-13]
Mechanical/Enclosure for Tympan with Shield/Export/Rev-B/ENCLOSURE_FOR_TYMPAN_WITH_SHIELD_TOP_REV-B.STEP
86.4 x 20.1 x 42.6 mm

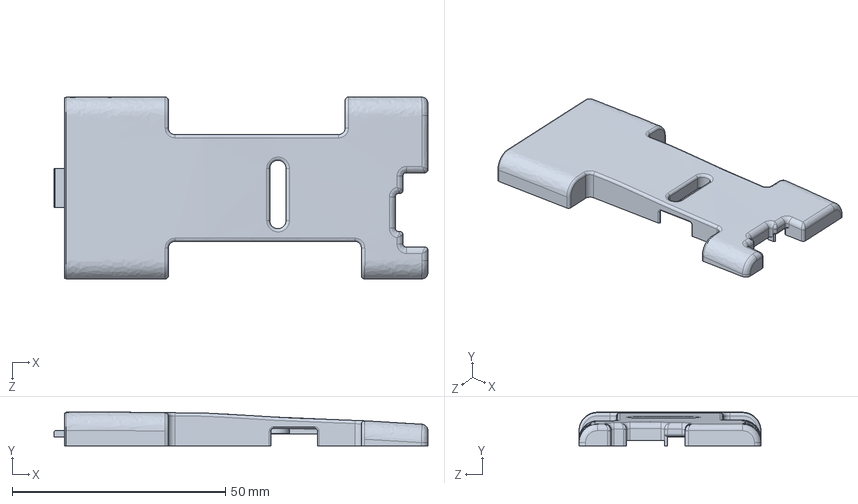
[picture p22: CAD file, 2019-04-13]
Mechanical/Enclosure for Tympan/Export/REV-B/TOP_COVER_OPENTACT_EXTENDED_D3_REV-B.STEP
87.7 x 7.88 x 42.6 mm

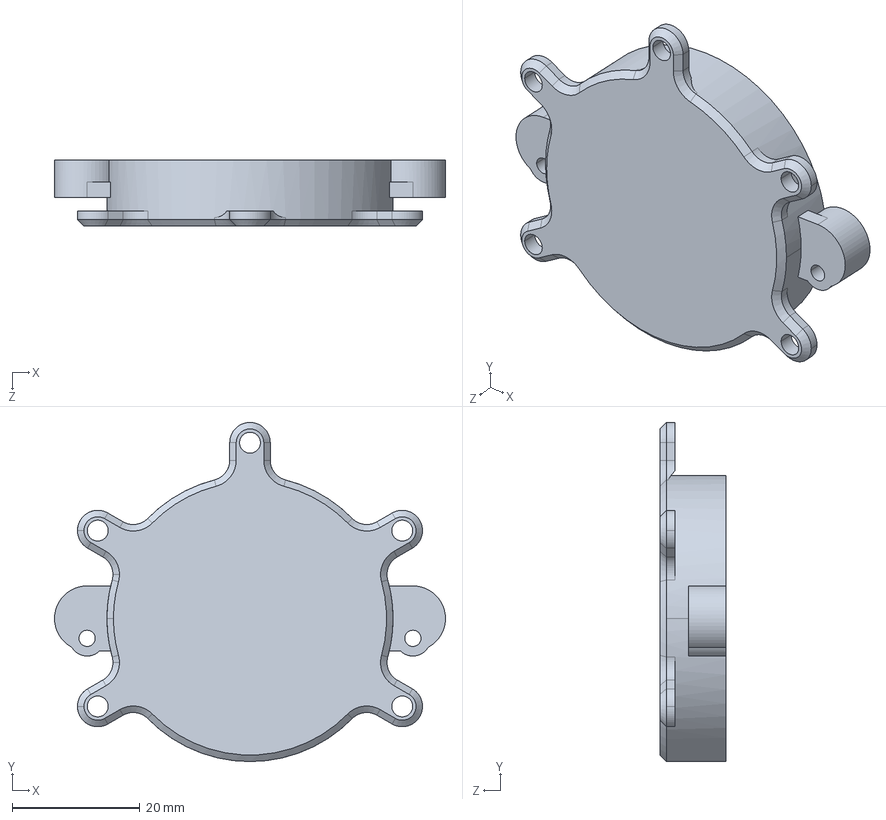
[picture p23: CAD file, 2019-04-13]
Mechanical/Speaker_Mount/Export/MOUNT_FOR_40MM_SPEAKER.STEP
61.2 x 53.1 x 10.4 mm

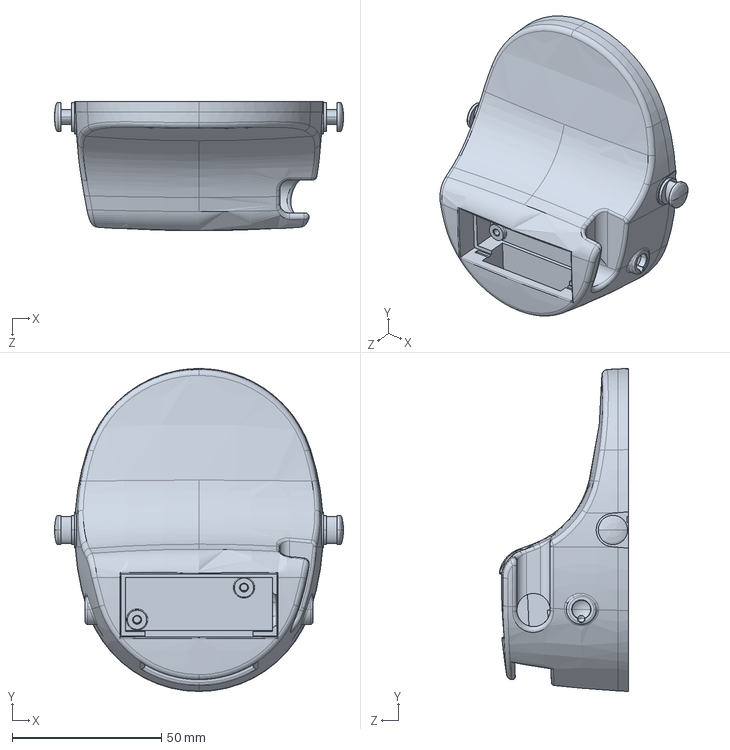
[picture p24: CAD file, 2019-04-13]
Mechanical/Earcup_Low-Profile/Export/REV-C/EARCUP_BODY_LEFT_LOW_PROFILE_REV-C.STEP
96.9 x 108.3 x 43.4 mm

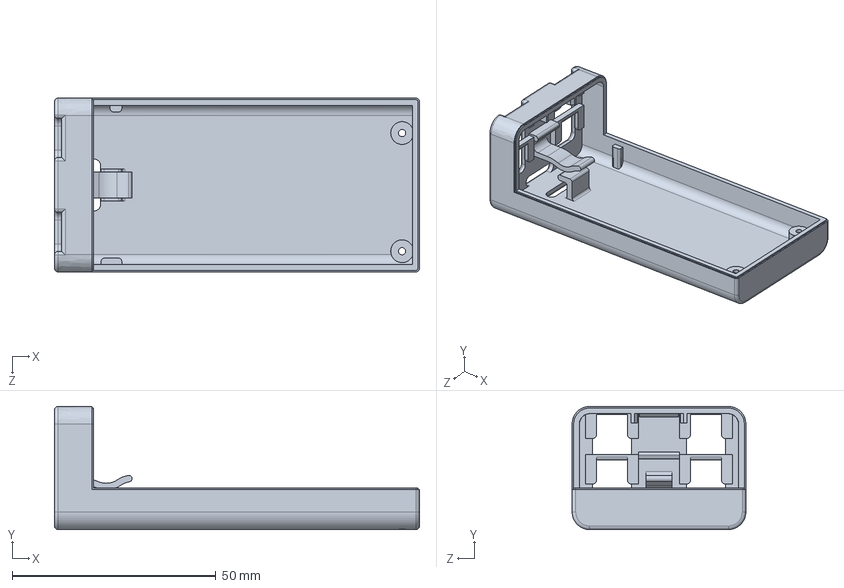
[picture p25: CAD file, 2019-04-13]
Mechanical/Enclosure for Tympan with Shield/Export/Rev-B/ENCLOSURE_FOR_TYMPAN_WITH_SHIELD_BOTTOM_REV-B.STEP
89.6 x 30.2 x 42.6 mm

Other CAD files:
Mechanical/Earcup_Full-Profile/Export/Rev-C/EARCUP_BODY_LEFT_FULL-PROFILE_REV-C.STEP
Mechanical/Earcup_with Pinna/Export/Rev-C/EARCUP_W_PINNA_ RIGHT_REV-C.stl
Mechanical/Earcup_Low-Profile/Export/REV-C/EARCUP_BODY_RIGHT_LOW_PROFILE_REV-C.STEP

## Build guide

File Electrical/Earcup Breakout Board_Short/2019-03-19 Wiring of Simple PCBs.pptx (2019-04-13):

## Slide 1

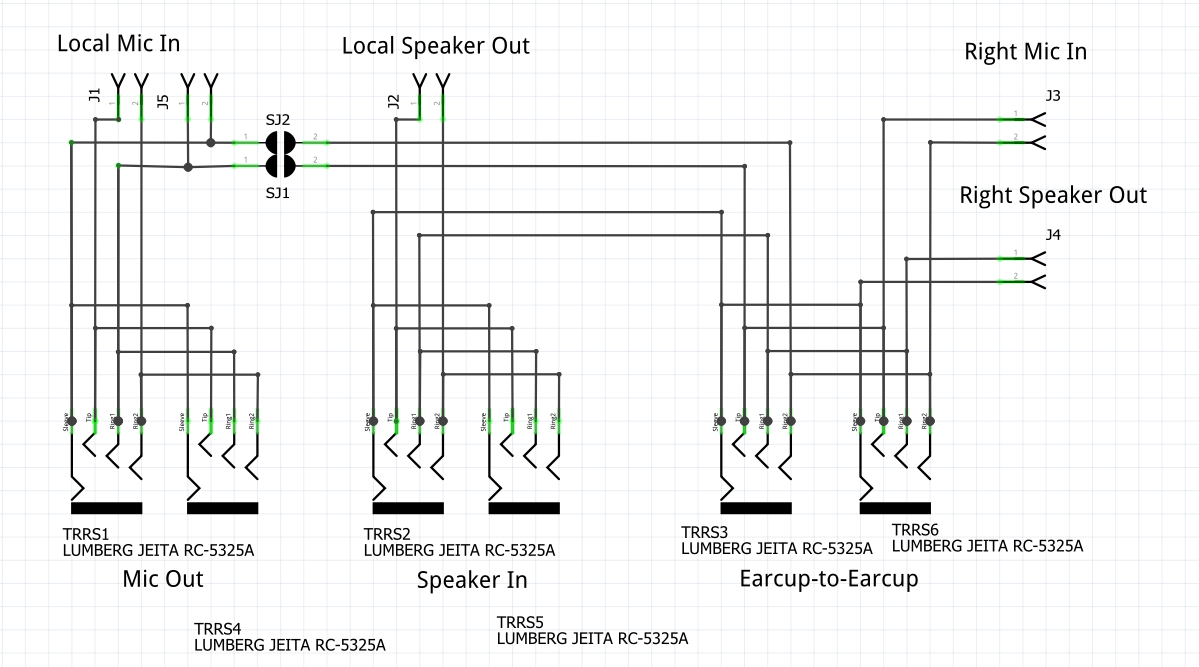
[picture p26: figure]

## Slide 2

Left Earcup

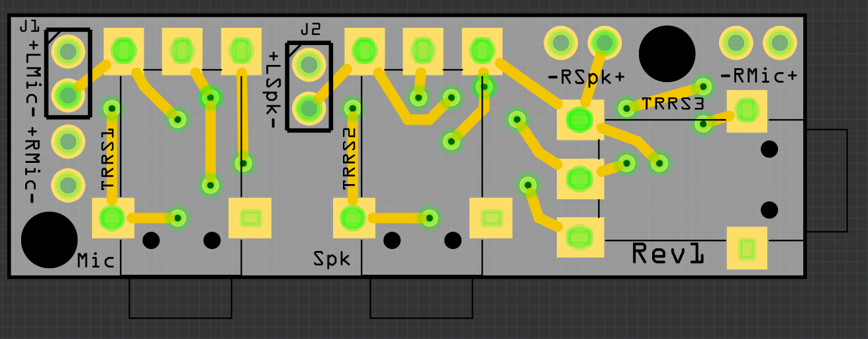
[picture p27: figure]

Jack

Jack

Jack

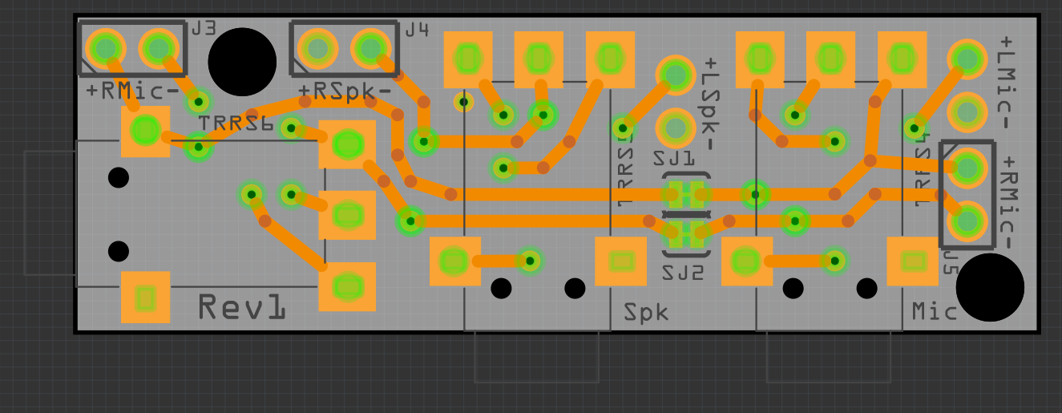
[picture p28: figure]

Right Earcup

Jack

No Jack

No Jack

Or, you can use these RMic inputs and NOT cut the traces.

Cut Traces

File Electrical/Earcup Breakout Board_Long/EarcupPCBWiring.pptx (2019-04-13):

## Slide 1

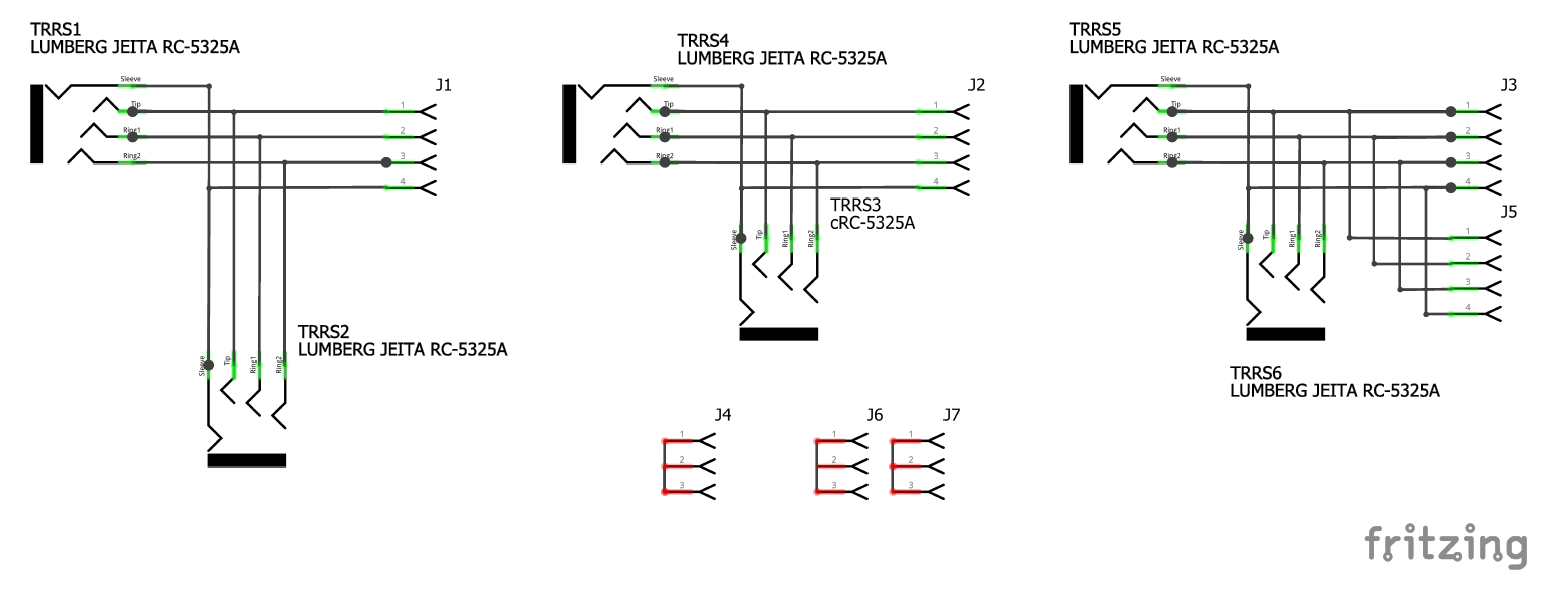
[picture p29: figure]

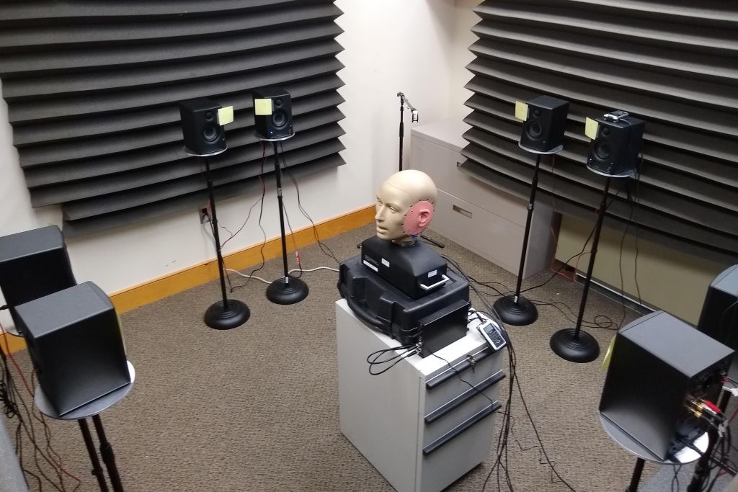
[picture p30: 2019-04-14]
Docs/Images/Testing_GRAS45CB/OpenEar-WholeSetup.jpg

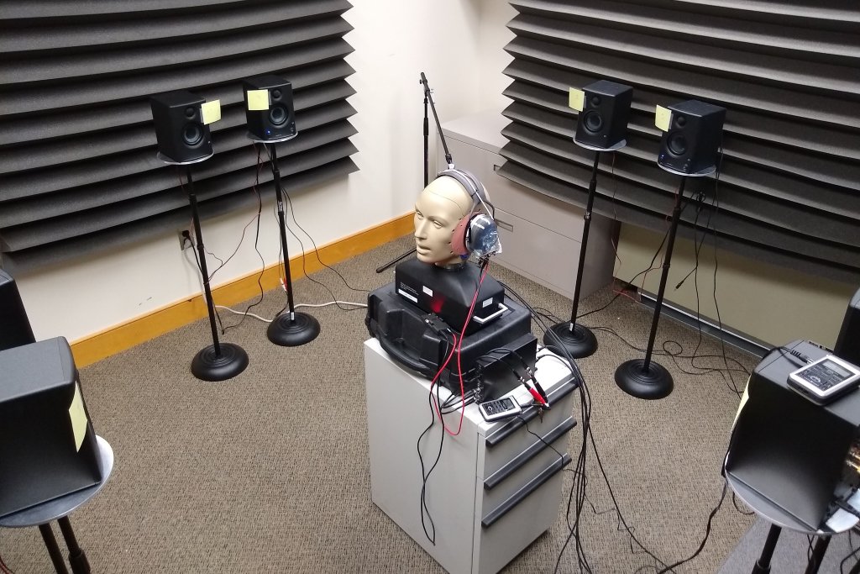
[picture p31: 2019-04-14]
Docs/Images/Testing_GRAS45CB/ClearEars-WholeSetup.jpg

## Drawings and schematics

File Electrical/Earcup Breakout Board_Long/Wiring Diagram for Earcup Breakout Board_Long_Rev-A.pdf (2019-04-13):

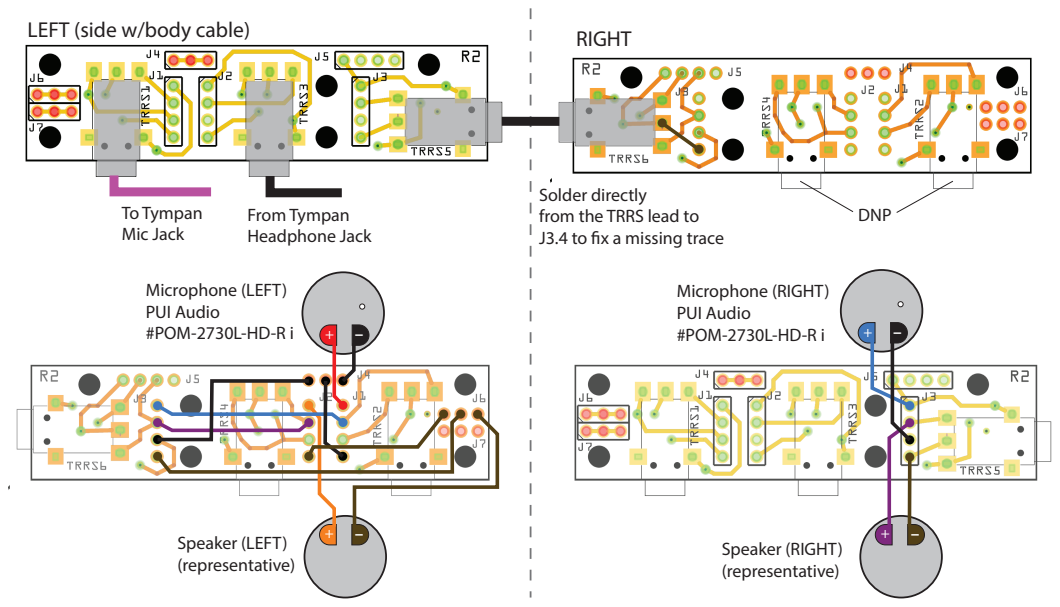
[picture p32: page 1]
LEFT (side w/body cable); RIGHT; DNP; Microphone (LEFT) PUI Audio; #POM-2730L-HD-R i; Microphone (RIGHT) PUI Audio #POM-2730L-HD-R i; (representative); Speaker (RIGHT) (representative); From Tympan Headphone Jack; To Tympan Mic Jack

Solder directly
from the TRRS lead to
J3.4 to x a missing trace

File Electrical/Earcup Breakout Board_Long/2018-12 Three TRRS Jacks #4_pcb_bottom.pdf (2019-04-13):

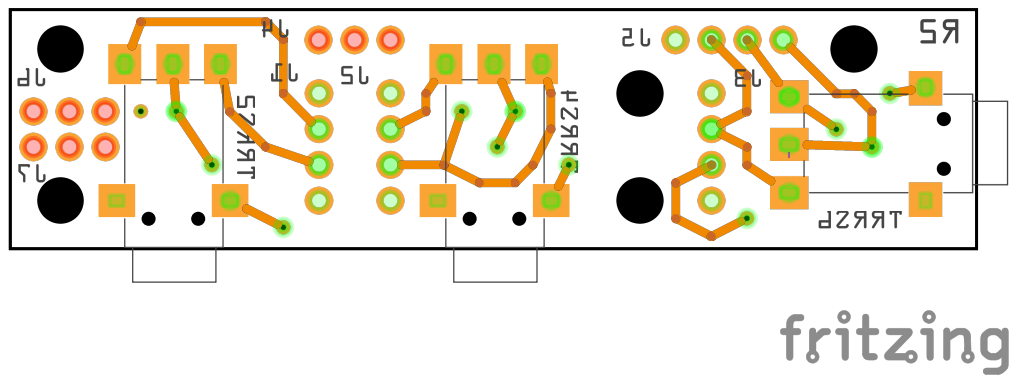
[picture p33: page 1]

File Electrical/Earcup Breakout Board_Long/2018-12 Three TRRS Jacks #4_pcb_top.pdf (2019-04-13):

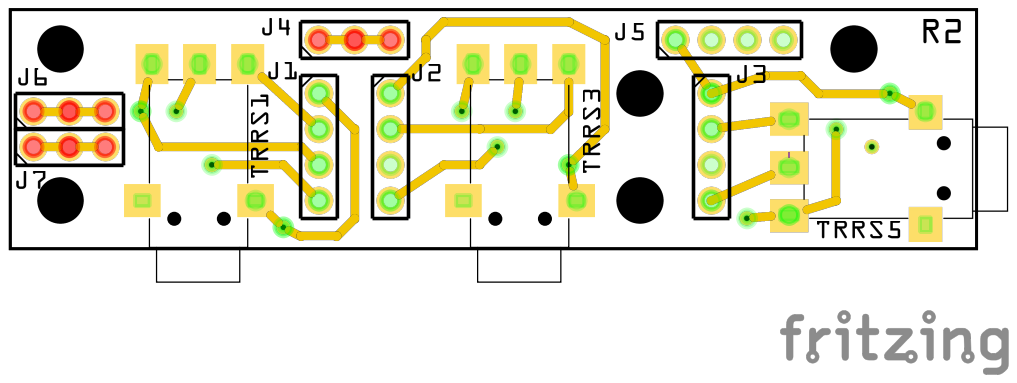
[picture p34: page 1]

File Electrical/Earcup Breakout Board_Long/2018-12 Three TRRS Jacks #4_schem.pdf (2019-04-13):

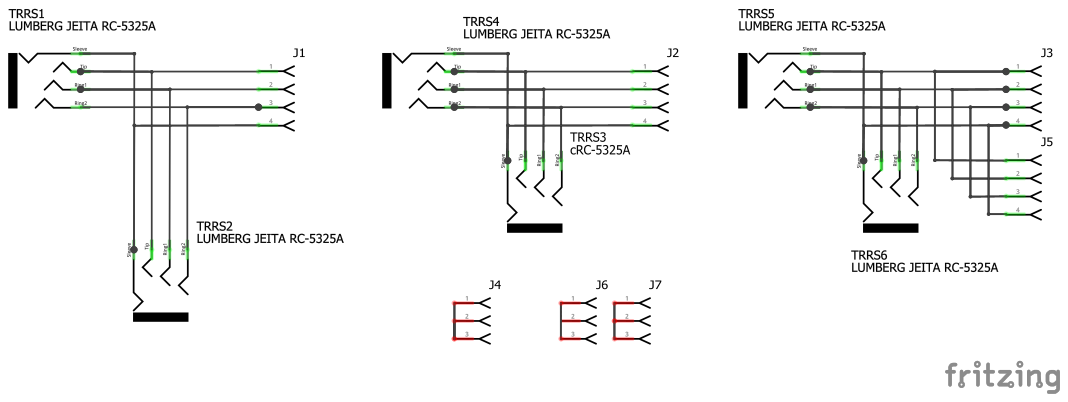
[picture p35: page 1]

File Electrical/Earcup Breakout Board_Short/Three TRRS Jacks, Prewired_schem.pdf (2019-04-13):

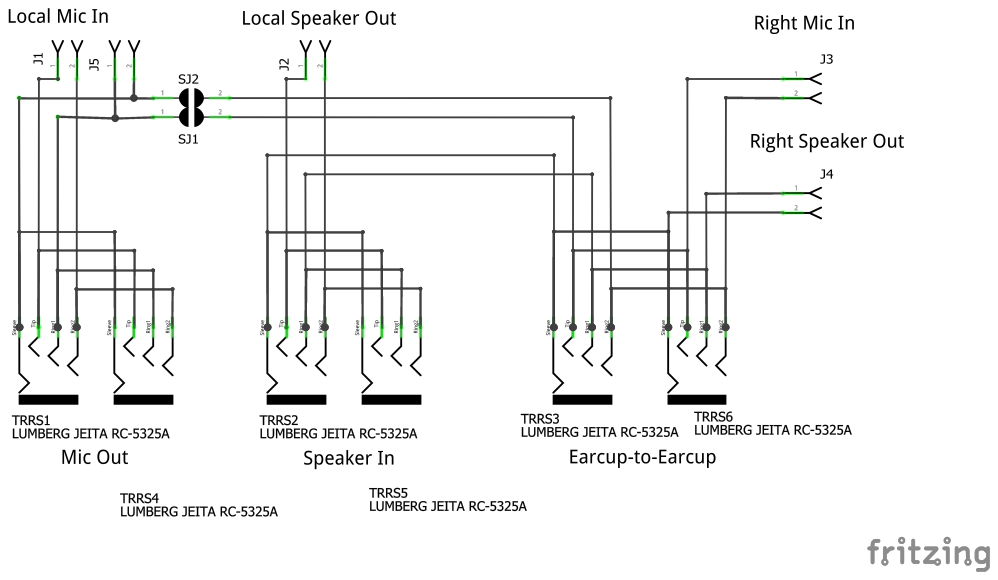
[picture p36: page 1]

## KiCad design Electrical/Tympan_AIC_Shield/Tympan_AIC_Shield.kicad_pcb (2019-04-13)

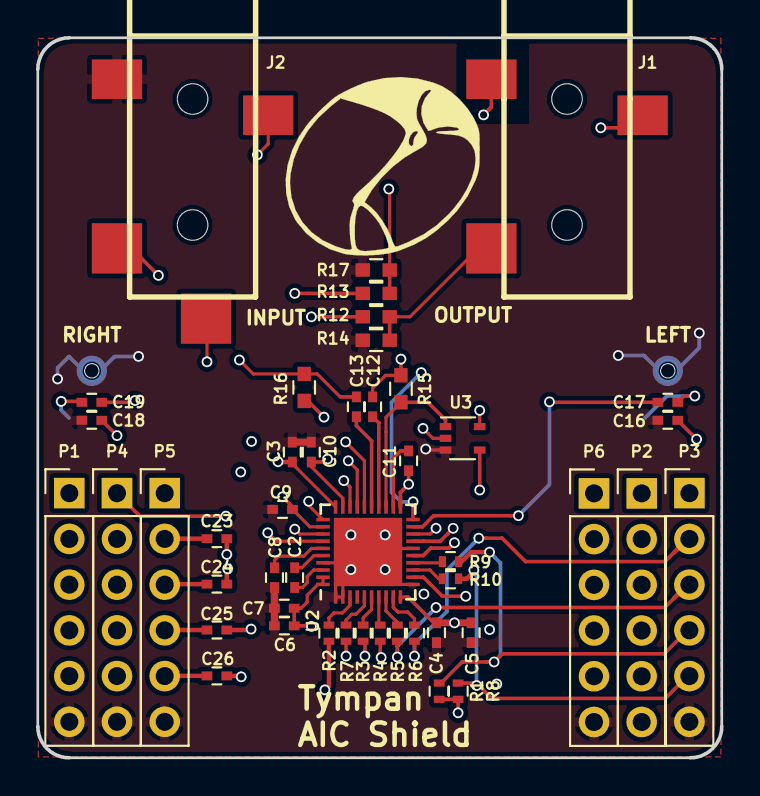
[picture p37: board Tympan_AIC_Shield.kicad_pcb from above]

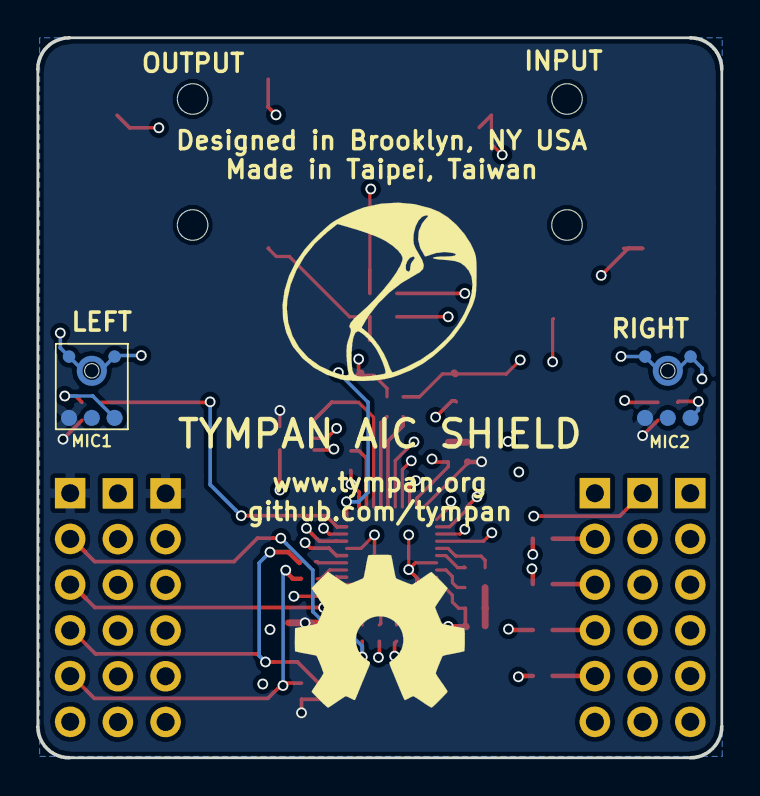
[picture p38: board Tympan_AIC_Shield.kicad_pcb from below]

Board: 4 copper layers, 38.0 x 40.0 mm, 48 parts (2 on the bottom side), 49 nets.

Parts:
C2, C8, C12, C13, C23, C24, C25, C26: 2.2uF; C_0402
C3, C5, C7, C10, C16, C18: 0.1uF; C_0402
C4, C6, C11: 10uF; C_0402
C9, C17, C19: 1uF; C_0402
J1: SJ-3523-SMT-TR
J2: SJ-3524-SMT-TR-PI; SJ-3524-SMT-TR
MIC1, MIC2: SPM0687LR5H-1
P1, P2, P3, P4, P5, P6: CONN_01X06; Pin_Header_Straight_1x06_Pitch2.54mm
R1, R8: 4K7; R_0402
R2, R3, R4, R5, R6, R7, R9, R10: 33R; R_0402
R12, R13: 0; C_0603
R14, R17: DNP; C_0603
R15, R16: 2.2K; C_0603
U2: TLV320AIC3206IRSBT; UQFN-40-1EP_5x5mm_Pitch0.4mm
U3: 74LVC1G66; SOT-353_SC-70-5

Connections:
+1V8: C6.1, C7.1, C9.1, C10.1, P1.1, P5.1, U2.29, U2.32, U2.39, U2.40
+3V3: C3.2, C4.2, C5.2, C16.2, C18.2, MIC1.4, MIC2.4, P3.1, P6.1, R1.2, R8.1, U2.10, U2.30, U3.5
/BCLK: P4.3, R3.1
/DIN_1: P3.3, R5.1
/DOUT_1: P3.2, R6.1
/HPL: R12.1, U2.31
/HPR: R13.1, U2.33
/IN1_L_1: C24.1, U2.17
/IN1_R_1: C23.1, U2.18
/IN2_L_1: C17.1, P6.2, U2.19
/IN2_R_1: C19.1, P6.3, U2.20
/LOL_1: C25.1, U2.26
/LOR_1: C26.1, U2.27
/MCLK: P4.2, R7.1
/MICBIAS: R15.1, U2.23, U3.1
/MICDET: J2.4, U2.34
/M_BIAS_1: P4.1, U3.4
/PDM_CLK1: P6.5, U2.12
/PDM_DAT1: P6.4, U2.15
/SCL2: P3.5, R8.2, R10.1
/SDA2: P3.4, R1.1, R9.1
/WCLK: P4.4, R4.1
/nRESET_1: P4.5, R2.1
GND: C3.1, C4.1, C5.1, C6.2, C7.2, C8.2, C9.2, C10.2, C11.2, C16.1, C18.1, J1.1, J2.1, MIC1.2, MIC1.3, MIC2.2, MIC2.3, P1.6, P3.6, P4.6, P5.6, P6.6, R14.2, R17.2, U2.1, U2.2, U2.11, U2.16, U2.21, U2.28, U2.37, U2.41, U3.3
unnamed: C2.1, U2.36
unnamed: C2.2, U2.38
unnamed: C8.1, U2.35
unnamed: C11.1, U2.22
unnamed: C12.1, U2.24
unnamed: C12.2, J2.2, R15.2
unnamed: C13.1, U2.25
unnamed: C13.2, J2.3, R16.1
unnamed: C17.2, MIC1.1
unnamed: C19.2, MIC2.1
unnamed: C23.2, P5.2
unnamed: C24.2, P5.3
unnamed: C25.2, P5.4
unnamed: C26.2, P5.5
unnamed: J1.2, R12.2, R14.1
unnamed: J1.3, R13.2, R17.1
unnamed: R2.2, U2.3
unnamed: R3.2, U2.6
unnamed: R4.2, U2.7
unnamed: R5.2, U2.8
unnamed: R6.2, U2.9
unnamed: R7.2, U2.5
unnamed: R9.2, U2.14
unnamed: R10.2, U2.13
unnamed: R16.2, U3.2

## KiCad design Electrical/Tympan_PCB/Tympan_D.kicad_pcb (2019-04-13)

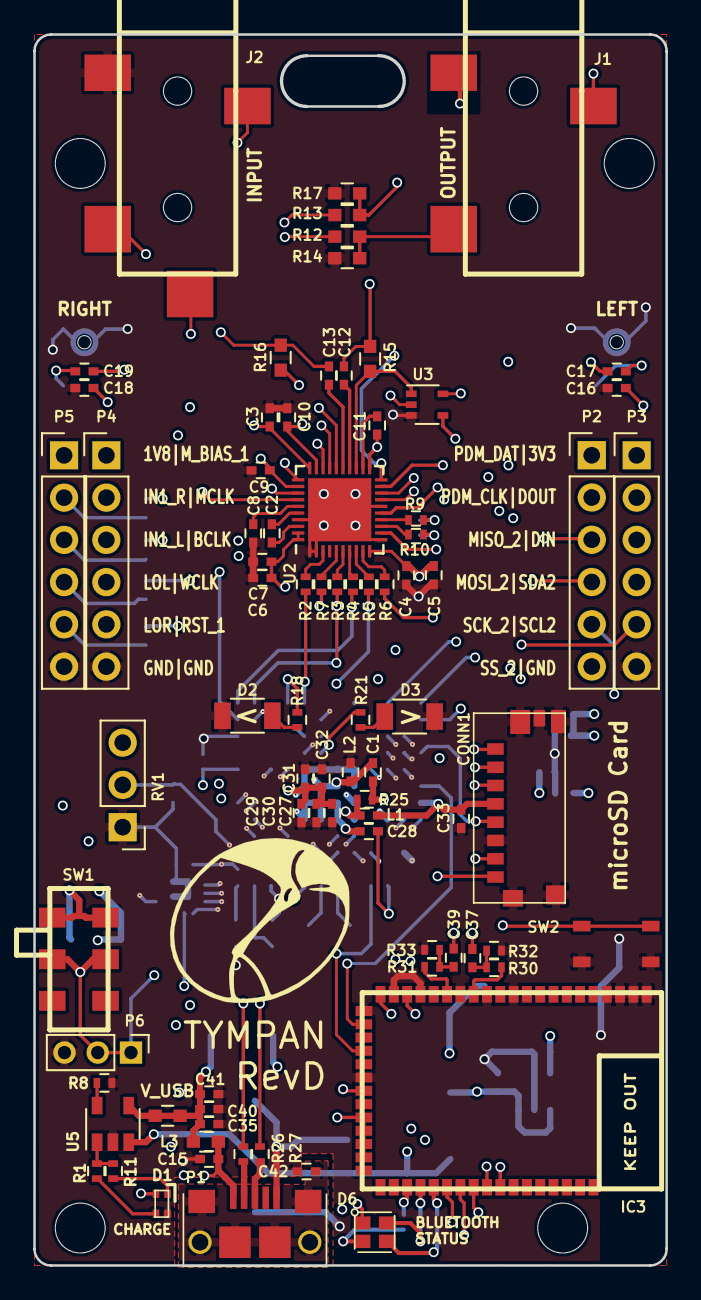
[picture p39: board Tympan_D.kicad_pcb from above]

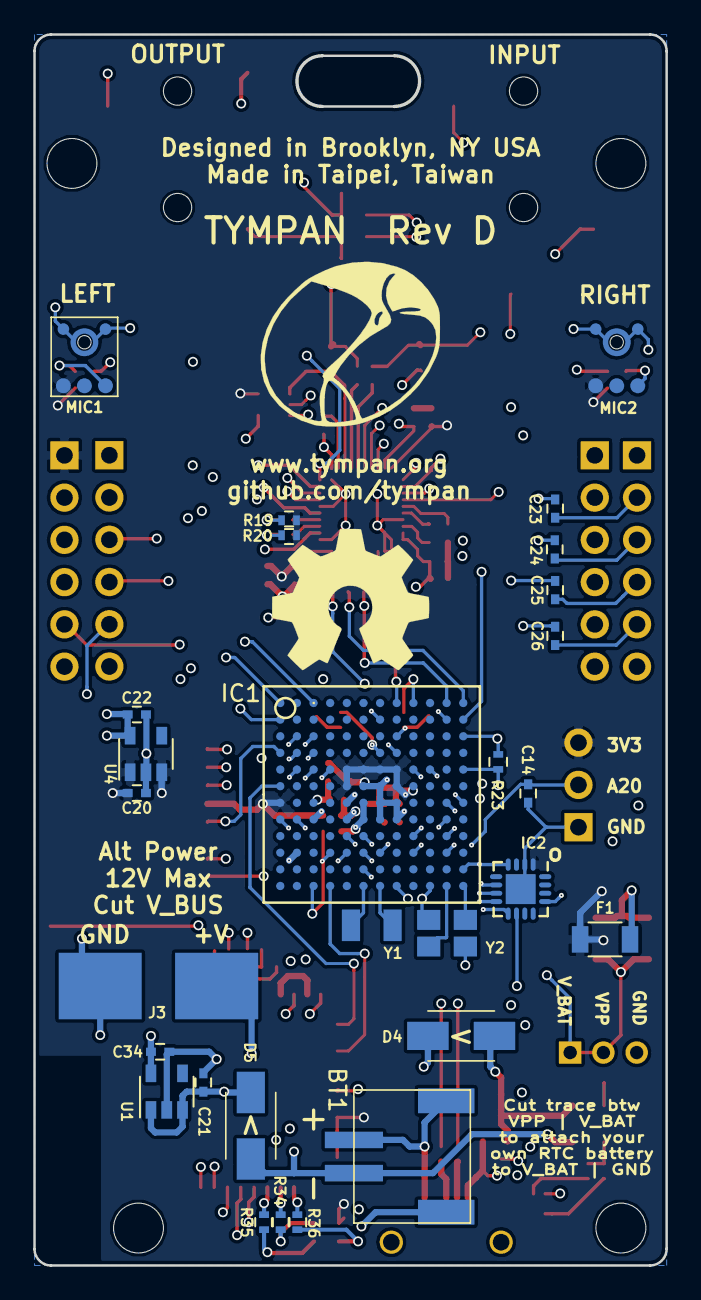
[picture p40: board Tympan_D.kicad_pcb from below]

Board: 4 copper layers, 38.0 x 74.0 mm, 113 parts (28 on the bottom side), 117 nets.

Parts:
BT1: 4UCON-20519; 4UCON-0217-20519
C1, C3, C5, C7, C10, C14, C16, C18, C28, C29, C42: 0.1uF; C_0402
C2, C8, C12, C13, C23, C24, C25, C26, C27, C32, C33, C37, C39: 2.2uF; C_0402
C4, C6, C11, C15: 10uF; C_0402
C9, C17, C19, C20, C21, C22, C34: 1uF; C_0402
C30, C31: 10nF; C_0402
C35: 4.7uF; C_0402
C40: 15pF; C_0402
C41: 22nF; C_0402
CONN1: 8_PIN_microSD; MOLEX_47571-0001
D1: APHB1608SGNC; ABHB1608S
D2, D3: LED; C_1206
D4, D5: Shottkey; ACDBA340-HF
D6: Led_RGB_CA; CLMVB-FKA-CFHEHLCBB7a363
F1: FUSE; C_1206
IC1: MK66FX1M0VMD18; BGA-144-1mm
IC2: MKL02Z32VFG4; QFN-16-1EP_3x3mm_Pitch0.5mm
IC3: BC127
J1: SJ-3523-SMT-TR
J2: SJ-3524-SMT-TR-PI; SJ-3524-SMT-TR
J3: alt Power Pads
L1, L2: 600R; C_0402
L3: 1K; C_0603
MIC1, MIC2: SPM0687LR5H-1
P1: USB_OTG; 10118193_microUSB
P2, P3, P4, P5: CONN_01X06; Pin_Header_Straight_1x06_Pitch2.54mm
P6: CONN_01X03; Pin_Header_Straight_1x03_Pitch2.00mm
P7: CONN_01X01; NPTH_2.4mm
P8, P9, P10: CONN_01X01; NPTH_3.2mm
R1, R11, R19, R20, R32, R33: 1K; R_0402
R2, R3, R4, R5, R6, R7, R9, R10, R26, R27: 33R; R_0402
R8: 2.2K; R_0402
R12, R13: 0R; C_0603
R14, R17: DNP; C_0603
R15, R16: 2.2K; C_0603
R18, R21, R34, R35, R36: 240R; R_0402
R23: 100K; R_0402
R25: 470R; R_0402
R30, R31: 10K; R_0402
RV1: POT; Pin_Header_Straight_1x03_Pitch2.54mm
SW1: CL-SB-22A
SW2: TACT_SWITCH; PTS810
U1: AP2210K-3.3TRG1; SOT-23-5
U2: TLV320AIC3206IRSBT; UQFN-40-1EP_5x5mm_Pitch0.4mm
U3: 74LVC1G66; SOT-353_SC-70-5
U4: LP5907MFX-1.8; SOT-23-5
U5: MCP73831; SOT-23-5
V_USB: DNP; C_0603
Y1: 32.768kHz; LFXTAL009678
Y2: 16MHz; FA_238_16.0000MB_K3

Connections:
+1V8: C6.1, C7.1, C9.1, C10.1, C22.1, P5.1, U2.29, U2.32, U2.39, U2.40, U4.5
+3V3: C3.2, C4.2, C5.2, C16.2, C18.2, C20.1, C27.1, C29.1, C30.1, C31.1, C32.1, C33.1, CONN1.4, D6.1, F1.2, IC1.E5, IC1.E6, IC1.E7, IC1.E8, IC1.F5, IC1.F8, IC1.G1, IC2.1, IC3.30, IC3.31, IC3.32, IC3.33, L1.2, MIC1.4, MIC2.4, P3.1, R19.1, R20.1, RV1.3, U2.10, U2.30, U3.5, U4.1, U4.3
+BATT: BT1.1, D5.2, J3.1, U5.3
/BCLK: IC1.A11, P4.3, R3.1
/BT_CTS: IC1.M8, IC3.40
/BT_PIO0: IC1.F1, IC3.23
/BT_PIO5: IC1.M4, IC3.25
/BT_RTS: IC1.K4, IC3.43
/BT_RX: IC1.E9, IC3.42
/BT_TX: IC1.E10, IC3.41
/BT_nRESET: IC1.K5, IC3.44
/CLK: CONN1.5, IC1.D1
/CMD: CONN1.3, IC1.E4
/DAT0: CONN1.7, IC1.D2
/DAT1: CONN1.8, IC1.D3
/DAT2: CONN1.1, IC1.E2
/DAT3: CONN1.2, IC1.E3
/DIN: IC1.B11, R5.1
/DIN_1: IC1.B12, P3.3
/DOUT: IC1.D8, R6.1
/DOUT_1: IC1.B7, P3.2
/HPL: R12.1, U2.31
/HPR: R13.1, U2.33
/IN1_L: C24.1, C37.1, U2.17
/IN1_R: C23.1, C39.1, U2.18
/IN2_L: C17.1, U2.19
/IN2_R: C19.1, U2.20
/LED_0: IC3.37, R36.1
/LED_1: IC3.38, R34.1
/LED_2: IC3.39, R35.1
/LOL: C25.1, IC3.21, U2.26
/LOR: C26.1, IC3.19, U2.27
/MCLK: IC1.C8, P4.2, R7.1
/MICBIAS: R15.1, U2.23, U3.1
/MICDET: J2.4, U2.34
/MISO_2: IC1.C2, P2.3
/MOSI_2: IC1.C3, P2.4
/M_BIAS: IC1.A3, U3.4
/M_BIAS_1: IC1.H11, P4.1
/PDM_CLK: P2.2, U2.12
/PDM_DAT: P2.1, U2.15
/POT: C14.1, IC1.K11, RV1.2
/PROG: IC2.10, SW2.1, SW2.2
/PTA0: IC1.J5, IC2.8
/PTA1: IC1.J6, IC2.6
/PTA2: IC1.K6, IC2.9
/PTA3: IC1.K7, IC2.7
/RESET_B: IC1.L12, IC2.4, IC2.13
/SCK_2: IC1.B1, P2.5
/SCL2: IC1.K9, P3.5
/SCL/SS: IC1.G12, R10.1, R20.2
/SDA2: IC1.J9, P3.4
/SDA/MOSI: IC1.G11, R9.1, R19.2
/SS_2: IC1.A1, P2.6
/USB: C15.1, D1.3, L3.1, P1.1
/USB0_D+: IC1.H1, R27.2
/USB0_D-: IC1.H2, R26.2
/VREGEN: IC1.E12, IC3.28, R23.1
/V_USB: C35.1, C40.1, C41.1, D4.2, L3.2, U5.4, V_USB.1, V_USB.2
/WCLK: IC1.A12, P4.4, R4.1
/nRESET: IC1.A8, R2.1
/nRESET_1: IC1.J11, P4.5
Earth: C42.2, P1.6, P1.7, P1.8, P1.9, P1.10, P1.11
GND: BT1.2, BT1.3, BT1.4, C3.1, C4.1, C5.1, C6.2, C7.2, C8.2, C9.2, C10.2, C11.2, C14.2, C15.2, C16.1, C18.1, C20.2, C21.2, C22.2, C27.2, C29.2, C30.2, C31.2, C32.2, C33.2, C34.2, C35.2, C40.2, C41.2, C42.1, CONN1.6, CONN1.9, CONN1.10, CONN1.11, CONN1.12, CONN1.13, D1.2, D2.1, D3.1, IC1.C12, IC1.F6, IC1.F7, IC1.G7, IC1.G8, IC1.H3, IC1.H7, IC1.H8, IC1.K2, IC1.M10, IC2.2, IC2.17, IC3.1, IC3.2, IC3.3, IC3.4, IC3.11, IC3.13, IC3.15, IC3.18, IC3.20, IC3.22, IC3.27, J1.1, J2.1, J3.2, L2.2, MIC1.2, MIC1.3, MIC2.2, MIC2.3, P1.5, P3.6, P4.6, P5.6, P6.3, R8.2, R14.2, R17.2, R23.2, R32.2, R33.2, RV1.1, SW2.3, SW2.4, U1.2, U2.1, U2.2, U2.11, U2.16, U2.21, U2.28, U2.37, U2.41, U3.3, U4.2, U5.2, Y2.2, Y2.4
unnamed: C1.1, C28.1, IC1.G6, IC1.H6, L2.1
unnamed: C1.2, IC1.G5, R25.1
unnamed: C2.1, U2.36
unnamed: C2.2, U2.38
unnamed: C8.1, U2.35
unnamed: C11.1, U2.22
unnamed: C12.1, U2.24
unnamed: C12.2, J2.2, R15.2
unnamed: C13.1, U2.25
unnamed: C13.2, J2.3, R16.1
unnamed: C17.2, MIC1.1
unnamed: C19.2, MIC2.1
unnamed: C21.1, D4.1, D5.1, U1.1, U1.3
unnamed: C23.2, P5.2
unnamed: C24.2, P5.3
unnamed: C25.2, P5.4
unnamed: C26.2, P5.5
unnamed: C28.2, IC1.M3
unnamed: C37.2, R30.2, R32.1
unnamed: C39.2, R31.2, R33.1
unnamed: D1.1, R11.1
unnamed: D1.4, R1.1
unnamed: D2.2, R18.2
unnamed: D3.2, R21.2
unnamed: D6.2, R34.2
unnamed: D6.3, R35.2
unnamed: D6.4, R36.2
unnamed: F1.1, SW1.1, SW1.4
unnamed: IC1.A9, R18.1
unnamed: IC1.D7, R21.1
unnamed: IC1.H5, L1.1, R25.2
unnamed: IC1.M6, Y1.1
unnamed: IC1.M7, Y1.2
unnamed: IC1.M11, Y2.1
unnamed: IC1.M12, Y2.3
unnamed: IC3.14, R30.1
unnamed: IC3.16, R31.1
unnamed: J1.2, R12.2, R14.1
unnamed: J1.3, R13.2, R17.1
unnamed: P1.2, R26.1
unnamed: P1.3, R27.1
unnamed: R1.2, R11.2, U5.1
unnamed: R2.2, U2.3
unnamed: R3.2, U2.6
unnamed: R4.2, U2.7
unnamed: R5.2, U2.8
unnamed: R6.2, U2.9
unnamed: R7.2, U2.5
unnamed: R8.1, U5.5
unnamed: R9.2, U2.14
unnamed: R10.2, U2.13
unnamed: R16.2, U3.2
VPP: C34.1, IC1.L6, P6.1, P6.2, SW1.2, SW1.5, U1.5

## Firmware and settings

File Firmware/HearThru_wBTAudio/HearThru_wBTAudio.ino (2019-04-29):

/*
   HeartThru with Bluetooth Audio

   Created: Chip Audette, OpenAudio, March 2019
   Purpose: Designed or use with OpenTact headsets and Tympan electronics.

   Features:
    * Electronic hear-thru with multiple algorithms
    * Remote control via Android App
    * Received audio over bluetooth

   MIT License.  use at your own risk.
*/


// Include all the of the needed libraries
#include <Tympan_Library.h>
#include <SparkFunbc127.h>  //from https://github.com/sparkfun/SparkFun_BC127_Bluetooth_Module_Arduino_Library

// State constants
const int AUDIO_MUTE=0, AUDIO_MONO=1, AUDIO_STEREO=2;
const int ALG_LINEAR=0, ALG_FASTCOMP=1, ALG_SLOWCOMP=2;
const int INPUT_PCBMICS=0, INPUT_MICJACK=1,INPUT_LINEIN_SE=2;

//define state
#define NO_STATE (-1)
class State_t {
  public:
    int input_source = NO_STATE;
    int audio = NO_STATE;
    int alg = NO_STATE;
};

//local files
#include "AudioSDWriter.h" 
#include "SerialManager.h"

//definitions for memory for SD writing
#define MAX_F32_BLOCKS (192)      //Can't seem to use more than 192, so you could set it to 192.  Won't run at all if much above 400.  


//set the sample rate and block size
const float sample_rate_Hz = 96000.0f ; //24000 or 44117 (or other frequencies in the table in AudioOutputI2S_F32)
const int audio_block_samples = 128;     //do not make bigger than AUDIO_BLOCK_SAMPLES from AudioStream.h (which is 128)  Must be 128 for SD recording.
AudioSettings_F32 audio_settings(sample_rate_Hz, audio_block_samples);

// Define the overall setup
String overall_name = String("Tympan: Multi-Mode Hear-Thru wBTAudio");
float default_input_gain_dB = 5.0f; //gain on the microphone
float input_gain_dB = default_input_gain_dB;
float vol_knob_gain_dB = 0.0; //will be overridden by volume knob, if used
float output_volume_dB = 0.0; //volume setting of output PGA

// Sparkfun Class for enabling BT Audio
BC127 BTModu(&Serial1); //which serial is connected to the BT module? Serial1 is.

// /////////// Define audio objects...they are configured later

//create audio library objects for handling the audio
Tympan                        myTympan(TympanRev::D);
AudioInputI2S_F32             i2s_in(audio_settings);   //Digital audio input from the ADC
AudioSDWriter_F32             audioSDWriter(audio_settings); //this is stereo by default
AudioMixer4_F32               inputMixerL(audio_settings),  inputMixerR(audio_settings);
AudioSwitch4_F32              inputSwitchL(audio_settings), inputSwitchR(audio_settings); //for switching between the algorithms
AudioEffectCompWDRC_F32       fastCompL(audio_settings),    fastCompR(audio_settings);  // fast compression
AudioEffectCompWDRC_F32       slowCompL(audio_settings),    slowCompR(audio_settings);  // slow compression
AudioMixer4_F32               outputMixerL(audio_settings), outputMixerR(audio_settings);  // for mixing together the diff algorithms
AudioOutputI2S_F32            i2s_out(audio_settings);  //Digital audio output to the DAC.  Should always be last.
  
//AUDIO CONNECTIONS...start with inputs
AudioConnection_F32           patchcord3(i2s_in, 0, inputMixerL, 0);     //Left audio to Left mixer 
AudioConnection_F32           patchcord4(i2s_in, 1, inputMixerL, 1);     //Right audio to Left mixer 
AudioConnection_F32           patchcord5(i2s_in, 0, inputMixerR, 0);     //Left audio to Right mixer
AudioConnection_F32           patchcord6(i2s_in, 1, inputMixerR, 1);     //Right audio to Right mixer
AudioConnection_F32           patchcord7(inputMixerL, 0, inputSwitchL, 0);   //connect left audio to switch
AudioConnection_F32           patchcord8(inputMixerR, 0, inputSwitchR, 0);  //connect right audio to switch

// Connections for Linear
AudioConnection_F32           patchcord100(inputSwitchL,ALG_LINEAR,outputMixerL,ALG_LINEAR); //pass the left signal through to the left output mixer
AudioConnection_F32           patchcord101(inputSwitchR,ALG_LINEAR,outputMixerR,ALG_LINEAR); //pass the right signal through to the right output mixer

//Connections for Fast Compression
AudioConnection_F32           patchcord200(inputSwitchL,ALG_FASTCOMP,fastCompL,0); //pass the left signal to left compressor
AudioConnection_F32           patchcord201(inputSwitchR,ALG_FASTCOMP,fastCompR,0); //pass the right signal to right compressor
AudioConnection_F32           patchcord202(fastCompL,0,outputMixerL,ALG_FASTCOMP); //pass the left signal to left compressor
AudioConnection_F32           patchcord203(fastCompR,0,outputMixerR,ALG_FASTCOMP); //pass the right signal to right compressor

//Connections for Slow Compression
AudioConnection_F32           patchcord300(inputSwitchL,ALG_SLOWCOMP,slowCompL,0); //pass the left signal to left compressor
AudioConnection_F32           patchcord301(inputSwitchR,ALG_SLOWCOMP,slowCompR,0); //pass the right signal to right compressor
AudioConnection_F32           patchcord302(slowCompL,0,outputMixerL,ALG_SLOWCOMP); //pass the left signal to left compressor
AudioConnection_F32           patchcord303(slowCompR,0,outputMixerR,ALG_SLOWCOMP); //pass the right signal to right compressor

//Connect to outputs
AudioConnection_F32           patchcord500(outputMixerL, 0, i2s_out, 0);    //Left mixer to left output
AudioConnection_F32           patchcord501(outputMixerR, 0, i2s_out, 1);    //Right mixer to right output

//Connect to SD logging
AudioConnection_F32           patchcord600(i2s_in, 0, audioSDWriter, 0);   //connect Raw audio to left channel of SD writer
AudioConnection_F32           patchcord601(i2s_in, 1, audioSDWriter, 1);   //connect Raw audio to right channel of SD writer

void setAlgorithmParameters(void) {
  { 
    //configure linear ... nothing to set!
  }

  //universal compression parameters
  float maxdB = 115.0;  //calibration factor.  What dB SPL is full scale?  For OpenTact at +5dB mic gain: 115dB in room results in FS.
  float exp_cr = 1.0, exp_end_knee = 0.0;    //expansion regime: compression ratio and knee point.  1.0 defeats this feature
  float tkgain = 0.0;     //compression-start gain (ie, gain of linear regime).

  {
    //configure fast compression
    float attack_ms = 5.0, release_ms = 100.0;
    float comp_ratio = 5.0; //compression regime: compression ratio
    float tk = 85.0;        //compression regime: compression knee point (dB SPL...related via maxdB)
    float bolt = 105.0;     //compression regime: output limiter
    
    fastCompL.setParams(attack_ms, release_ms, maxdB, exp_cr, exp_end_knee, tkgain, comp_ratio, tk, bolt);
    fastCompR.setParams(attack_ms, release_ms, maxdB, exp_cr, exp_end_knee, tkgain, comp_ratio, tk, bolt);   
  }
  {
    //configure slow compression
    float attack_ms = 3000.0, release_ms = 3000.0;
    float comp_ratio = 5.0; //compression regime: compression ratio
    float tk = 80.0;        //compression regime: compression knee point (dB SPL...related via maxdB)
    float bolt = 110.0;     //compression regime: output limiter
    
    slowCompL.setParams(attack_ms, release_ms, maxdB, exp_cr, exp_end_knee, tkgain, comp_ratio, tk, bolt);
    slowCompR.setParams(attack_ms, release_ms, maxdB, exp_cr, exp_end_knee, tkgain, comp_ratio, tk, bolt);   
  }
}

//control display and serial interaction
bool enable_printCPUandMemory = false;
void togglePrintMemoryAndCPU(void) { enable_printCPUandMemory = !enable_printCPUandMemory; }; //"extern" let's be it accessible outside
void setPrintMemoryAndCPU(bool state) { enable_printCPUandMemory = state; };
bool enable_printAveSignalLevels = false;
bool printAveSignalLevels_as_dBSPL = false;
void togglePrintAveSignalLevels(bool as_dBSPL) { enable_printAveSignalLevels = !enable_printAveSignalLevels; printAveSignalLevels_as_dBSPL = as_dBSPL;};
SerialManager serialManager;
#define BOTH_SERIAL myTympan

//keep track of state
State_t myState;

int current_config = 0;
void setConfiguration(int config) { 
  
  myTympan.volume_dB(-60.0); delay(50);  //mute the output audio
  myState.input_source = config;
  
  switch (config) {
    case INPUT_PCBMICS:
      //Select Input
      myTympan.inputSelect(TYMPAN_INPUT_ON_BOARD_MIC); // use the on-board microphones

      //Set input gain to 0dB
      input_gain_dB = 15;
      myTympan.setInputGain_dB(input_gain_dB);

      //Store configuration
      current_config = INPUT_PCBMICS;
      break;
      
    case INPUT_MICJACK:
      //Select Input
      myTympan.inputSelect(TYMPAN_INPUT_JACK_AS_MIC); // use the mic jack
      myTympan.setEnableStereoExtMicBias(true);

      //Set input gain to 0dB
      input_gain_dB = default_input_gain_dB;
      myTympan.setInputGain_dB(input_gain_dB);

      //Store configuration
      current_config = INPUT_MICJACK;
      break;
      
    case INPUT_LINEIN_SE:
      //Select Input
      myTympan.inputSelect(TYMPAN_INPUT_LINE_IN); // use the line-input through holes

      //Set input gain to 0dB
      input_gain_dB = default_input_gain_dB;
      myTympan.setInputGain_dB(input_gain_dB);

      //Store configuration
      current_config = INPUT_LINEIN_SE;
      break;
  }

  //bring the output volume back up
  delay(50);  myTympan.volume_dB(output_volume_dB);  // output amp: -63.6 to +24 dB in 0.5dB steps.  uses signed 8-bit
}

// ///////////////// Main setup() and loop() as required for all Arduino programs

// define the setup() function, the function that is called once when the device is booting
void setup() {
  delay(100);
  
  myTympan.beginBothSerial(); delay(1000);
  BOTH_SERIAL.print(overall_name);BOTH_SERIAL.println(": setup():...");
  BOTH_SERIAL.print("Sample Rate (Hz): "); BOTH_SERIAL.println(audio_settings.sample_rate_Hz);
  BOTH_SERIAL.print("Audio Block Size (samples): "); BOTH_SERIAL.println(audio_settings.audio_block_samples);

  //allocate the audio memory
  AudioMemory_F32_wSettings(MAX_F32_BLOCKS,audio_settings); //I can only seem to allocate 400 blocks
  BOTH_SERIAL.println("Setup: memory allocated.");
  
  //activate the Tympan audio hardware
  myTympan.enable();        // activate AIC
  
  //temporariliy mute the system
  myTympan.volume_dB(-60.0);  // output amp: -63.6 to +24 dB in 0.5dB steps.  uses signed 8-bit
  float cutoff_Hz = 70.0;  //set the default cutoff frequency for the highpass filter
  myTympan.setHPFonADC(true, cutoff_Hz, audio_settings.sample_rate_Hz); //set to false to disble

  //setup the audio processing
  setAlgorithmParameters();
  setAudioStereo();
  setAudioLinear();

  //Configure for Tympan PCB mics
  BOTH_SERIAL.println("Setup: Using Mic Jack with Mic Bias.");
  setConfiguration(INPUT_MICJACK); //this will also unmute the system
 
  //update the potentiometer settings
	//servicePotentiometer(millis());

  //service BT Audio
  serviceBTAudio();

  //Set the Bluetooth audio to go straight to the headphone amp, not through the Tympan software
  myTympan.mixBTAudioWithOutput(true);

  //prepare the SD writer for the format that we want and any error statements
  audioSDWriter.setSerial(&myTympan);
  audioSDWriter.setWriteDataType(AudioSDWriter::WriteDataType::INT16);  //this is the built-in the default, but here you could change it to FLOAT32
  audioSDWriter.setNumWriteChannels(2);             //this is also the defaullt, but you could set it to 2
 
  //End of setup
  BOTH_SERIAL.println("Setup: complete.");serialManager.printHelp();

} //end setup()

// define the loop() function, the function that is repeated over and over for the life of the device


void loop() {
  //asm(" WFI");  //save power by sleeping.  Wakes when an interrupt is fired (usually by the audio subsystem...so every 256 audio samples)

  //respond to Serial commands
  while (Serial.available()) serialManager.respondToByte((char)Serial.read());   //USB Serial
  while (Serial1.available()) serialManager.respondToByte((char)Serial1.read()); //BT Serial
  
  //service the SD recording
  serviceSD();

  //update the memory and CPU usage...if enough time has passed
  if (enable_printCPUandMemory) printCPUandMemory(millis());

  serviceLEDs();
  
  //print info about the signal processing
  //updateAveSignalLevels(millis());
  //if (enable_printAveSignalLevels) printAveSignalLevels(millis(),printAveSignalLevels_as_dBSPL);

} //end loop()



// ///////////////// Servicing routines

void serviceBTAudio(void) {
  // resetFlag tracks the state of the module. When true, the module is reset and
  //  ready to receive a connection. When false, the module either has an active
  //  connection or has lost its connection; checking connectionState() will verify
  //  which of those conditions we're in.
  static boolean resetFlag = false;

  // This is where we determine the state of the module. If resetFlag is false, and
  //  we have a CONNECT_ERROR, we need to restart the module to clear its pairing
  //  list so it can accept another connection.
  if (BTModu.connectionState() == BC127::CONNECT_ERROR  && !resetFlag)
  {  
    Serial.println("Connection lost! Resetting...");
    // Blast the existing settings of the BC127 module, so I know that the module is
    //  set to factory defaults...
    BTModu.restore();

    // ...but, before I restart, I need to set the device to be a SINK, so it will
    //  enable its audio output and dump the audio to the output.
    BTModu.setClassicSink();

    // Write, reset, to commit and effect the change to a source.
    BTModu.writeConfig();
    // Repeat the connection process if we've lost our connection.
    BTModu.reset();
    // Change the resetFlag, so we know we've restored the module to a usable state.
    resetFlag = true;
  }
  // If we ARE connected, we'll issue the "PLAY" command. Note that issuing this when
  //  we are already playing doesn't hurt anything.
  else {
    //BTModu.musicCommands(BC127::PLAY);
  }

  // We want to look for a connection to be made to the module; once a connection
  //  has been made, we can clear the resetFlag.
  if (BTModu.connectionState() == BC127::SUCCESS) resetFlag = false;

}


void printCPUandMemory(unsigned long curTime_millis) {
  static unsigned long updatePeriod_millis = 3000; //how many milliseconds between updating gain reading?
  static unsigned long lastUpdate_millis = 0;

  //has enough time passed to update everything?
  if (curTime_millis < lastUpdate_millis) lastUpdate_millis = 0; //handle wrap-around of the clock
  if ((curTime_millis - lastUpdate_millis) > updatePeriod_millis) { //is it time to update the user interface?
    printCPUandMemoryMessage();  
    lastUpdate_millis = curTime_millis; //we will use this value the next time around.
  }
}
void printCPUandMemoryMessage(void) {
    BOTH_SERIAL.print("CPU Cur/Pk: ");
    BOTH_SERIAL.print(audio_settings.processorUsage(),1);
    BOTH_SERIAL.print("%/");
    BOTH_SERIAL.print(audio_settings.processorUsageMax(),1);
    BOTH_SERIAL.print("%, ");
    BOTH_SERIAL.print("MEM Cur/Pk: ");
    BOTH_SERIAL.print(AudioMemoryUsage_F32());
    BOTH_SERIAL.print("/");
    BOTH_SERIAL.print(AudioMemoryUsageMax_F32());
    BOTH_SERIAL.println();
}

void serviceLEDs(void) {
  if (audioSDWriter.getState() == AudioSDWriter::STATE::UNPREPARED) {
    myTympan.setRedLED(HIGH); myTympan.setAmberLED(HIGH); //Turn ON both
  } else if (audioSDWriter.getState() == AudioSDWriter::STATE::RECORDING) {
    myTympan.setRedLED(LOW); myTympan.setAmberLED(HIGH); //Go Amber
  } else {
    myTympan.setRedLED(HIGH); myTympan.setAmberLED(LOW); //Go Red
  }
}

#define PRINT_OVERRUN_WARNING 1   //set to 1 to print a warning that the there's been a hiccup in the writing to the SD.
void serviceSD(void) {
  if (audioSDWriter.serviceSD()) {
    //if we're here, data was written to the SD, so do some checking of the timing...
  
    //print a warning if there has been an SD writing hiccup
    if (PRINT_OVERRUN_WARNING) {
      if (audioSDWriter.getQueueOverrun() || i2s_in.get_isOutOfMemory()) {
        float blocksPerSecond = ((float)audio_settings.sample_rate_Hz) / ((float)(audio_settings.audio_block_samples));
        BOTH_SERIAL.print("SD Write Warning: there was a hiccup in the writing.  Approx Time (sec): ");
        BOTH_SERIAL.println( ((float)audioSDWriter.getNBlocksWritten()) / blocksPerSecond );
      }
    }

    //print timing information to help debug hiccups in the audio.  Are the writes fast enough?  Are there overruns?
    if (PRINT_FULL_SD_TIMING) {
      Serial.print("SD Write Status: "); 
      Serial.print(audioSDWriter.getQueueOverrun()); //zero means no overrun
      Serial.print(", ");
      Serial.print(AudioMemoryUsageMax_F32());  //hopefully, is less than MAX_F32_BLOCKS
      //Serial.print(", ");
      //Serial.print(MAX_F32_BLOCKS);  // max possible memory allocation
      Serial.print(", ");
      Serial.println(i2s_in.get_isOutOfMemory());  //zero means i2s_input always had memory to work with.  Non-zero means it ran out at least once.
      
      //Now that we've read the flags, reset them.
      AudioMemoryUsageMaxReset_F32();
    }
    
    audioSDWriter.clearQueueOverrun();
    i2s_in.clear_isOutOfMemory();
  } else {
    //no SD recording currently, so no SD action
  }
}


// //////////////////////////////////// Control the audio processing from the SerialManager
//here's a function to change the volume settings.   We'll also invoke it from our serialManager
void incrementInputGain(float increment_dB) {
  input_gain_dB += increment_dB;
  if (input_gain_dB < 0.0) {
    BOTH_SERIAL.println("Error: cannot set input gain less than 0 dB.");
    BOTH_SERIAL.println("Setting input gain to 0 dB.");
    input_gain_dB = 0.0;
  }
  myTympan.setInputGain_dB(input_gain_dB);
}

void setAudioMute(void) {
  myState.audio = AUDIO_MUTE;
  inputMixerL.gain(0, 0.0);      inputMixerL.gain(1, 0.0); //mute left and right input to left side
  inputMixerR.gain(0, 0.0);      inputMixerR.gain(1, 0.0); //mute left and right input to the right side
}
void setAudioMono(void) {
  myState.audio = AUDIO_MONO;
  inputMixerL.gain(0, 0.5);      inputMixerL.gain(1, 0.5);  //50% left and 50% right to the left side
  inputMixerR.gain(0, 0.5);      inputMixerR.gain(1, 0.5);  //50% left and 50% right to the right side
}
void setAudioStereo(void) {
  myState.audio = AUDIO_STEREO;
  inputMixerL.gain(0, 1.0);      inputMixerL.gain(1, 0.0); //100% left to left side
  inputMixerR.gain(0, 0.0);      inputMixerR.gain(1, 1.0); //100% right to the right side
}
void setAudioLinear(void) {
  myState.alg = ALG_LINEAR;
  inputSwitchL.setChannel(ALG_LINEAR);  inputSwitchR.setChannel(ALG_LINEAR);
}
void setAudioFastComp(void) {
  myState.alg = ALG_FASTCOMP;
  inputSwitchL.setChannel(ALG_FASTCOMP);  inputSwitchR.setChannel(ALG_FASTCOMP);
}
void setAudioSlowComp(void) {
  myState.alg = ALG_SLOWCOMP;
  inputSwitchL.setChannel(ALG_SLOWCOMP);  inputSwitchR.setChannel(ALG_SLOWCOMP);
}

void scaleCompressionSpeed(float scale_value, bool print_new_vals) {
  switch (myState.alg) {
    case ALG_LINEAR:
      BOTH_SERIAL.println("LINEAR: Ignoring change command.");
      break;
   case ALG_FASTCOMP:
      incrementAttackRelease(scale_value,fastCompL,fastCompR,print_new_vals);
      //printAttackRelease(fastCompL);
      break;
   case ALG_SLOWCOMP:
      incrementAttackRelease(scale_value,slowCompL,slowCompR,print_new_vals);
      //printAttackRelease(slowCompL);
  }
}
void incrementAttackRelease(float scale_value,AudioEffectCompWDRC_F32 &compL, AudioEffectCompWDRC_F32 &compR,bool print_new_vals) {
  float attack_msec = compL.getAttack_msec();
  float release_msec = compL.getRelease_msec();
  float min_attack_msec = 2.0, min_release_msec = 50;
  attack_msec = max(min_attack_msec,attack_msec*scale_value);
  release_msec = max(min_release_msec,release_msec*scale_value);
  compL.setAttackRelease_msec(attack_msec,release_msec);
  compR.setAttackRelease_msec(attack_msec,release_msec);
  if (print_new_vals) {
    BOTH_SERIAL.print("Comp: "); BOTH_SERIAL.print((int)attack_msec); BOTH_SERIAL.print("ms attack, ");
    BOTH_SERIAL.print((int)release_msec); BOTH_SERIAL.println("ms release");
  }
}
void incrementKneepoint(float increment_dB,bool print_new_vals) {
  switch (myState.alg) {
    case ALG_LINEAR:
      BOTH_SERIAL.println("LINEAR: Ignoring change command.");
      break;
   case ALG_FASTCOMP:
      incrementKneepoint(increment_dB,fastCompL,fastCompR,print_new_vals);
      break;
   case ALG_SLOWCOMP:
      incrementKneepoint(increment_dB,slowCompL,slowCompR,print_new_vals);
  }
}
void incrementKneepoint(float increment_dB,AudioEffectCompWDRC_F32 &compL, AudioEffectCompWDRC_F32 &compR,bool print_new_vals) {
  float knee_dB = compL.getKneeCompressor_dBSPL();
  float min_knee_dB = 0.0;
  knee_dB = max(min_knee_dB,knee_dB+increment_dB);
  compL.setKneeCompressor_dBSPL(knee_dB);
  compR.setKneeCompressor_dBSPL(knee_dB);
  if (print_new_vals) {
    BOTH_SERIAL.print("Comp: Kneepoint set to "); BOTH_SERIAL.print((int)knee_dB); BOTH_SERIAL.println("dB");
  }
}

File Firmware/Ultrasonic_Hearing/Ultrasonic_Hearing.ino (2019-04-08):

/*
  Tympan_Ultrasound

  Created: Chip Audette (OpenAudio), Feb 2017

  Purpose: Sample fast enough (96 kHz) to acquire ultrasound signals (up to 48 kHz)
      then do single side-band shifting of the signals down to the audible range

  Uses Teensy Audio Adapter ro the Tympan Audio Board
      For Teensy Audio Board, assumes microphones (or whatever) are attached to the
      For Tympan Audio Board, can use on board mics or external mic

  User Controls:
    Potentiometer on Tympan controls the amount of frequency shift

   MIT License.  use at your own risk.
*/

//do stereo processing?
#define USE_STEREO 1

//definitions for SD writing
#define MAX_F32_BLOCKS (192)      //Can't seem to use more than 192, so you could set it to 192.  Won't run at all if much above 400.  

// Include all the of the needed libraries
#include <Tympan_Library.h> //for AudioConvert_I16toF32, AudioConvert_F32toI16, and AudioEffectGain_F32
#include "SDAudioWriter.h"
#include "SerialManager.h"

const float sample_rate_Hz = 96000.0f ; //24000 or 44117.64706f (or other frequencies in the table in AudioOutputI2S_F32
const int audio_block_samples = 128;  //do not make bigger than AUDIO_BLOCK_SAMPLES from AudioStream.h
AudioSettings_F32   audio_settings(sample_rate_Hz, audio_block_samples);

// Define the overall setup
String overall_name = String("Tympan: Ultrasound Listening");
float default_input_gain_dB = 5.0f; //gain on the microphone
float input_gain_dB = default_input_gain_dB;
float vol_knob_gain_dB = 0.0; //will be overridden by volume knob
float ultrasound_gain_dB = 5.0;

// /////////// Define audio objects...they are configured later

//create audio library objects for handling the audio
TympanPins                  tympPins(TYMPAN_REV_D3); //TYMPAN_REV_C or TYMPAN_REV_D
TympanBase                  audioHardware(tympPins);
AudioInputI2S_F32           i2s_in(audio_settings);  //Digital audio *from* the Teensy Audio Board ADC.  Sends Int16.  Stereo.
AudioSynthWaveformSine_F32  carrier(audio_settings);   
AudioRecordQueue_F32        queueL(audio_settings), queueR(audio_settings);     //gives access to audio data (will use for SD card)

AudioEffectGain_F32         preGainL(audio_settings), preGainR(audio_settings);   
AudioFilterBiquad_F32       iirL1(audio_settings), iirL2(audio_settings), iirR1(audio_settings), iirR2(audio_settings);         
AudioMathMultiply_F32       multiplyL(audio_settings), multiplyR(audio_settings);  
AudioMixer4_F32             mixerL(audio_settings), mixerR(audio_settings);
AudioEffectCompWDRC_F32     fastCompL(audio_settings), fastCompR(audio_settings);      
AudioOutputI2S_F32          i2s_out(audio_settings);        //Digital audio *to* the Teensy Audio Board DAC.  Expects Int16.  Stereo

//Connect Left & Right Input Channel to Left and Right SD card queue
AudioConnection_F32           patchcord1001(i2s_in, 0, queueL, 0);   //connect Raw audio to queue (to enable SD writing)
AudioConnection_F32           patchcord1002(i2s_in, 1, queueR, 0);  //connect Raw audio to queue (to enable SD writing)

//Make all of the audio connections for the left audio channel
AudioConnection_F32         patchCord20(i2s_in, 0, mixerL, 0);  //raw path for hear-thru
AudioConnection_F32         patchCord1(i2s_in, 0, preGainL, 0); //processed path for ultrasound
AudioConnection_F32         patchCord2(preGainL, 0, iirL1, 0);
AudioConnection_F32         patchCord3(iirL1, 0, iirL2, 0);
AudioConnection_F32         patchCord10(iirL2, 0, multiplyL, 0);
AudioConnection_F32         patchCord4(carrier, 0, multiplyL, 1);
AudioConnection_F32         patchCord21(multiplyL, 0, mixerL, 1);  //end of ultrasound path
AudioConnection_F32         patchCord27(mixerL, 0, fastCompL, 0); //compression for whatever audio we're sending to the ears
AudioConnection_F32         patchCord5(fastCompL, 0, i2s_out, 0); //send to left output
//AudioConnection_F32         patchCord27(mixerL, 0, i2s_out, 0);  //send to left output

#if USE_STEREO
  //make all of the audio connections for the right audio channel
  AudioConnection_F32         patchCord2000(i2s_in, 1, mixerR, 0); //raw path for hear-thru
  AudioConnection_F32         patchCord101(i2s_in, 1, preGainR, 0); //processed path for ultrasound
  AudioConnection_F32         patchCord200(preGainR, 0, iirR1, 0);
  AudioConnection_F32         patchCord300(iirR1, 0, iirR2, 0);
  AudioConnection_F32         patchCord1000(iirR2, 0, multiplyR, 0);
  AudioConnection_F32         patchCord400(carrier, 0, multiplyR, 1);
  AudioConnection_F32         patchCord2100(multiplyR, 0, mixerR, 1);  //end of ultrasound path
  //AudioConnection_F32         patchCord2110(mixerR, 0, fastCompR, 0); //compression for whatever audio we're sending to the ears
  //AudioConnection_F32         patchCord500(fastCompR, 0, i2s_out, 1); //send to right output
  AudioConnection_F32         patchCord2110(mixerR,0,i2s_out,1);
#else
  //copy the left channel over to the right channel (ie, mono)
  //AudioConnection_F32         patchCord6(compWDRC_L, 0, i2s_out, 1);
  AudioConnection_F32         patchCord6(fastCompL, 0, i2s_out, 1);
#endif

//set the recording configuration
const int config_pcb_mics = 20;
const int config_mic_jack = 21;
const int config_line_in_SE  = 22;

int current_config = 0;
void setConfiguration(int config) { 
  switch (config) {
    case config_pcb_mics:
      //Select Input
      audioHardware.setInputGain_dB(0); delay(100); //make quieter
      audioHardware.inputSelect(TYMPAN_INPUT_ON_BOARD_MIC); // use the on-board microphones

      //Set input gain to 0dB
      input_gain_dB = 15;
      audioHardware.setInputGain_dB(input_gain_dB);

      //Store configuration
      current_config = config_pcb_mics;
      break;
      
    case config_mic_jack:

      //Select Input
      audioHardware.setInputGain_dB(0); delay(100); //make quieter
      audioHardware.inputSelect(TYMPAN_INPUT_JACK_AS_MIC); // use the mic jack
      audioHardware.setEnableStereoExtMicBias(true);

      //Set input gain to desired value
      input_gain_dB = default_input_gain_dB;
      audioHardware.setInputGain_dB(input_gain_dB);

      //Store configuration
      current_config = config_mic_jack;
      break;
      
    case config_line_in_SE:
      
      //Select Input
      audioHardware.setInputGain_dB(0); delay(100); //make quieter
      audioHardware.inputSelect(TYMPAN_INPUT_LINE_IN); // use the line-input through holes

      //Set input gain to desired value
      input_gain_dB = default_input_gain_dB;
      audioHardware.setInputGain_dB(input_gain_dB);

      //Store configuration
      current_config = config_line_in_SE;
      break;
  }
}
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

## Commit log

2019-04-10 Firmware: Device can now set its own icon in the remote app.
2019-04-12 HearThru: add maxdB calibration
2019-04-13 Initial release of design documentation.
    [02-Earcup TRRS Simple PCB R1.step, 2018-12 Three TRRS Jacks #4.fzz, 2018-12 Three TRRS Jacks.fzz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]
2019-04-13 Added eDrawing files to preview CAD witout Solidworks. Noted this in the read me.
    [EARCUP_W_PINNA_ RIGHT_REV-C.stl]
2019-04-13 Update BOM_Low Profile Earcup Assy.xlsx
    Added cost for AIC shield
    [BOM_Low Profile Earcup Assy.xlsx]
